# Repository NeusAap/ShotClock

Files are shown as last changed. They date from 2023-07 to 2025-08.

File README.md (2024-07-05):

# ShotClock hardware & software
This project entails the creation of a poker shot clock. The device is designed to manage the timing of player decisions during a poker game, enhancing the pace of play and ensuring fair timing for all participants. 

# Folder structure
1. `doc`: Contains design documents & notes/questions
2. `hw/ShotClockProject`: Contains KiCAD 7.0.6 design files for hardware
3. `hw/ShotClockProject/output`: Contains hardware output files (plots, PDFs etc.)
4. `sw`: contains STM32CubeIDE firmware

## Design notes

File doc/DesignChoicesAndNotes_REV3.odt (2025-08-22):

Shotclock design choices / notes / tasks REV 3

A product that displays a countdown timer on seven segment displays once a button has been pressed. The countdown will show a maximum of 99 seconds (2 digits), and each of these 2 digits should be present on 4 sides of the product (so a total of 8 seven segment displays).

A buzzer is added to audibily hear when the timer has ran out.

The product is designed to have a ‘main pcb’, which houses most electrical components. On each 90 degree edge of the main PCB, there will be a connector that connects to a set of 2 seven segment display digits.

See requirements below for more info.

The REV2 boards & encasing:

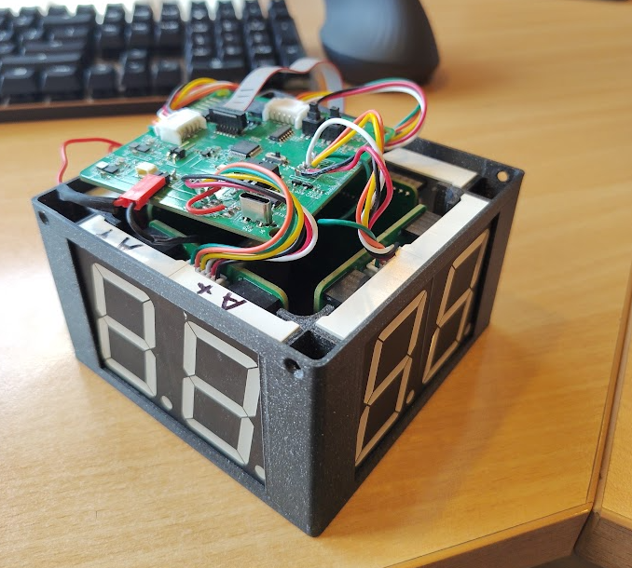
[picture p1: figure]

This document only contains updates, tasks etc for REV3! The information for REV2 is in the other .odt file.

# Updated requirements REV2 -> REV3

1. Battery powered, rechargable

1.1 USB type C, product must keep functioning while charging!

2. New buttons with new seperate connectors instead of buttons on PCB

3. More relaxed fitment in the encasing to reduce stress on the PCBs and the segment displays

# Research notes

## Notes for charging while using product

BQ25895 as charging IC is a good option

TPS61288RQQR as a high current buck converter

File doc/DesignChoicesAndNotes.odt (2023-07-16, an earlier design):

Shotclock design choices / notes

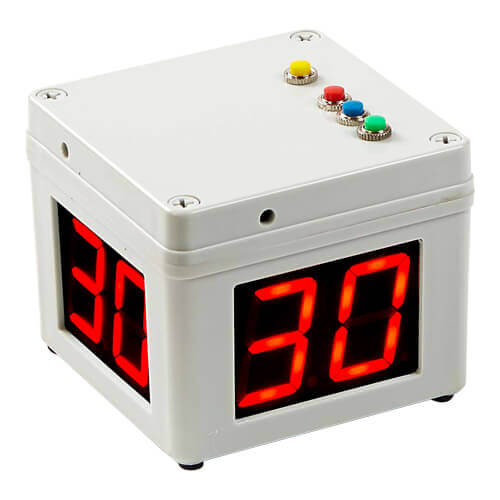
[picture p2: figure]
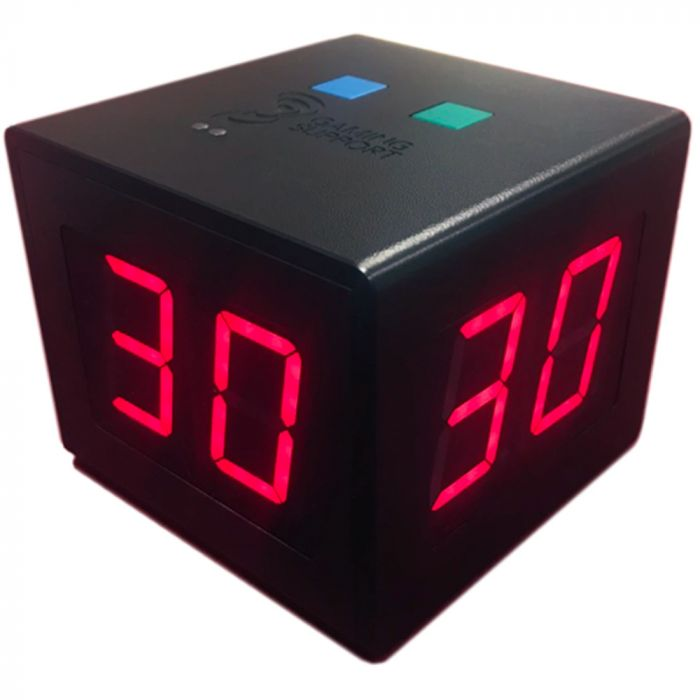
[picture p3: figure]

A product that displays a countdown timer on seven segment displays once a button has been pressed. The countdown will show a maximum of 99 seconds (2 digits), and each of these 2 digits should be present on 4 sides of the product (so a total of 8 seven segment displays).

A buzzer is added to audibily hear when the timer has ran out.

The product is designed to have a ‘main pcb’, which houses most electrical components. On each 90 degree edge of the main PCB, there will be a connector that connects to a set of 2 seven segment display digits.

See requirements below for more info.

# Requirements

1. Battery powered, rechargable

1.1 Li-Po would be nice, since large capacity and shitload of form factors

1.2 USB type C connector as charge plug (charging may stop usage of product if using li-po)

1.3 USB type C connector as USB D+/D- to MCU

2. Can drive 2x4 seven (actually, eight segment. They have a dot.) segment displays, with brightness control

3. LED to display battery < 20%

4. LED to display charging status (‘is charging’ and ‘is done charging’)

5. Switch (latching) to turn product on and off, while still being able to charge product (preferably in both the on and off state. But only off state is also fine for version 1).

6. Three functional buttons (momentary) with hardware debouncing

7. STM32 MCU, with SWD connector

8. UART header

9. Bootloader button to STM

10. Buzzer to indicate that the timer has ran out.

11. EEPROM to store user settings (atleast countdown time and buzzer on/off). So RTC registers of STM should be good enough.

# Battery charger & ADC charge status

## General info pages used

TP4056 as charging IC (https://dlnmh9ip6v2uc.cloudfront.net/datasheets/Prototyping/TP4056.pdf)

Page used on deciding charge current:

https://www.xtar.cc/news/What-Is-The-Best-Charging-Current-And-How-To-Calculate-The-Charging-Time-Of-Lithium-Battery-154.html

Disable system while charging battery:

https://www.microtype.io/lithium-ion-battery-charger-circuit-load-sharing/

Choosing battery of 1500 or 2000 mAh, since it is good middle-way between size, weight, price and capacity (should last the product more than long enough to be able to only charge it when systemload is off).

I got these in house: https://nl.aliexpress.com/i/1005005148897780.html?gatewayAdapt=glo2nld

With a thermistor in them. Calculations for this temp pin are in TEMP Pin NTC: R1, R2 calculation.

There will a 3 pin JST connector.

I’ve also added an extra 2 pin connector, since a load of cells don’t have a thermistor in them. A jumper is also present to pull the TEMP pin to ground, if no thermistor is to be used.

## TEMP Pin NTC: R1, R2 calculation

The batteries I have, have a 10k NTC at room temp. I don’t know the specifics, because it is a chinese battery, without good datasheet. Internet says “10K NTC usually has 3977K Thermistor Beta Value” (https://www.eevblog.com/forum/projects/ntc-thermistor-resistance-(li-ion-charging)/).

The datasheet of the TP4056 mentions: “If TEMP pin’s voltage is below 45% or above 80% of supply voltage VIN for more than 0.15S, this means temp is to low or high”.

So if assuming that the following is true:

For 45°C the thermistor resistance is about 4k2.

For 5°C the thermistor resistance is about 26k.

(at ambient room temp of +/- 20°C, the resistance was about 7k8, measured myself, so this assumption sounds about right)

I’ve converted the resistance calculator from above post: https://www.best-microcontroller-projects.com/tp4056-page2.html into Python code (inserted as OLE object, also found on my GitHub):

Then using the following input values for the Python script:

vratio1 = 0.45

vratio2 = 0.80

ratio_tol1 = 0.01

ratio_tol2 = 0.05

Rntc_min = 4200

Rntc_max = 26000

Gives the following closest E48 resistors (just as in the article. Atleast I know how to calculate this now hahaha):

r1 4780 r2 86600 Rntc1 4.2e3 Rntc2 26e3

I am also adding a jumper, to switch off the whole functionality as well. Both to support 2 pinned batteries, and to disable the temp sensing, if these assumption and/or calculations are wrong.

## Battery charge reading & battery lvl status LED

To read the amount of charge in the battery, I want to use the ADC of the STM32.

This article was used as example: https://vivonomicon.com/2019/10/15/reading-battery-voltage-with-the-stm32s-adc/

It mentions that: “if you use smaller resistor values for the voltage divider, you use more current, but the sampling can be faster”. A commentor on that post replied: “You can use larger resistors (i.e. 1M) in the divider and still use short sampling times if you add a small capacitor (1n-100n). [between the Analog pin and ground, to buffer so the ADC peripheral gets current more quickly. Instead of via the high resistance path of the voltage divider]”.

So that is what is implemented. A 1:1 voltage division (a single Lithium cell get to a max of 4.2V, so divided by 2 will give a max of 2.1V, which the analog pins easily accept), with large resistance values (1M) and a 100n capacitor between the analog ADC peripheral and GND.

Max current leakage would be:

4.2 = I * 2000000

I = 0.0000021 amps (or 2.1 microamps).

Should be reasonable for a 1500mAh battery (or is it smart to increase the resistance values & capacitor value even more, to reduce the current leakage even more?).

And for the battery level status led:

Assuming a forward voltage drop of 2.0 volts and a forward current of 10 mA, we can calculate the resistor value using Ohm's Law (V = IR).

Rearranging the formula, we get R = V / I.

R = (Vsupply - Vf) / I

R = (3.3V - 2.0V) / 0.01A

R = +/- 130 Ω (130 is closest E48 std. value.)

# Voltage regulator (3v3)

TPS63000, variable output DC/DC buck boost.

Variable output calculation

From datasheet:

8.2.2 Detailed Design Procedure

8.2.2.1 Programming the Output Voltage

“Within the TPS6300x family, there are fixed and adjustable output voltage versions available. To properly configure the fixed output voltage devices, the FB pin is used to sense the output voltage. This means that it must be connected directly to VOUT. At the adjustable output voltage versions, an external resistor divider is used to adjust the output voltage. The resistor divider must be connected between VOUT, FB and GND. When the output voltage is regulated properly, the typical value of the voltage at the FB pin is 500 mV. The maximum recommended value for the output voltage is 5.5 V. The current through the resistive divider should be about 100 times greater than the current into the FB pin. The typical current into the FB pin is 0.01 μA, and the voltage across the resistor between FB and GND, R2 , is typically 500 mV. Based on those two values, the recommended value for R2 should be lower than 500 kΩ, in order to set the divider current at 1 μA or higher. TI recommends to keep the value for this resistor in the range of 200 kΩ. From that, the value of the resistor connected between VOUT and FB, R1 , depending on the needed output voltage (VOUT), can be calculated using Equation 1. (1) If as an example, an output voltage of 3.3 V is needed, a 1-MΩ resistor should be chosen for R1 . To improve control performance using a feedforward capacitor in parallel to R1 is recommended. The value for the feedforward capacitor can be calculated using Equation 2.”

This data from the datasheet has been used to calculate R2 and Cff, see R2 calculation and Cff calculation.

## R2 calculation

Wanted Vout is 3v3.

R1 = 1M (according to datasheet 8.2.2.1)

R2 = ?

Vout = 3.3V

Vfb = 0.5V (typical value from datasheet 8.2.2.1)

Solving for R2:

R2 = (Vfb * R1) / (Vout - Vfb )

R2 = (0.5 * 1000000) / (3.3 – 0.5) = 178571,4285714286 ohms.

Solved for Vout (to make sure I did not make a solving mistake):

Vout = (Vfb * (R1 + R2) ) / R2

Vout = (0.5 * (1000000 + 178000)) / 178000 = 3,308988764044944 = 3.3v.

So chosen R2 = 178k.

## Cff calculation

2.2us = 0.0000022 s

R1 = 1000000 ohm

Cff = 2.2us / R1 = 0.0000022 / 1000000 = 0.0000000000022 F

0.0000000000022 F = 2.2 pF

So Cff should be 2.2pF

# Vbat pin on MCU

I’d like to connect the Vbat pin on the MCU, to the Li-Ion battery. This way I don’t have to put an extra coin-cell in, and I can still use the RTC functionality on the MCU.

The datasheet mentions the following important information on the RTC and backup registers (2.3.16, but I’ve marked important keywords here):

“+/- 2.2 uA power usage at 3v3 (see figure 16 of datasheet)

VBAT Backup operating voltage min: 1.8V and max 3.6V.

The RTC and the backup registers are supplied through a switch that takes power either on VDD supply when present or through the VBAT pin. The backup registers are forty-two 16-bit registers used to store 84 bytes of user application data when VDD power is not present. They are not reset by a system or power reset, and they are not reset when the device wakes up from the Standby mode. The real-time clock provides a set of continuously running counters which can be used with suitable software to provide a clock calendar function, and provides an alarm interrupt and a periodic interrupt. It is clocked by a 32.768 kHz external crystal, resonator or oscillator, the internal low-power RC oscillator or the high-speed external clock divided by 128. The internal low-speed RC has a typical frequency of 40 kHz. The RTC can be calibrated using an external 512 Hz output to compensate for any natural quartz deviation. The RTC features a 32-bit programmable counter for long term measurement using the Compare register to generate an alarm. A 20-bit prescaler is used for the time base clock and is by default configured to generate a time base of 1 second from a clock at 32.768 kHz.”

So:

1. No higher than 3.6V (Li-Po can get up to 4.2V, so we need a lower voltage).

2. Low power consumption, which is nice. LDO would be good option

3. 84 bytes of user data is more than enough. This means no extra EEPROM chip is needed.

4. Can be clocked by internal clock, or High-Speed External. Since I see no use for a really precise, non-drifting clock, this means that I can omit the 32.768kHz crystal from the design.

Only problem, is the voltage.

A voltage division would probably not work here, since the voltage would keep changing when the battery drains. This would probably give weird clock issues (I don’t need a really stable RTC clock, but a sort-off stable RTC would be nice).

So next best option would probably to use a small LDO. The RTC pin does not use to much current, so the inefficiency does not matter to much.

LD39015M33R is chosen, since this has input range of 1.8 to 5.5v and a stable output of 3v3. Very low quiescent current (18 µA typ. at no load, 38 µA typ. at 150 mA load, 1 µA max. in OFF mode) and also 150mA output current, which should be way more than enough.

# Momentary buttons and hardware debouncing

I want 3 digital input momentary buttons, with hardware debouncing integrated into the PCB.

Schmitt Trigger IC chosen for debouncing: STM m74hc14yrm13tr.

Because the internet said this IC is great for button removing hysterisis at 3v3 levels since it is a really fast schmitt trigger IC. The IC doesn’t need additional configuration. Also the IC is ok in terms of availability.

https://www.st.com/resource/en/datasheet/m74hc14.pdf

I’ve used ‘snapeda.com’ to create a schematic symbol (footprint was already available). Quite useful stuff: https://www.snapeda.com/parts/M74HC14YRM13TR/STMicroelectronics/view-part/

# Buzzer

To make sure the buzzer does not pull to much current from the MCU, an NPN transistor is used:

Also a flyback diode is placed between buzzer pins, to act as a bypass if the magnetic field collapses, to not damage the transistor.

A current limiting resistor of 1k ohm is used for the base pin of the transistor.

Then 3v3 is connected to GND, via the transistor.

Since the chosen buzzer (see Footprint / part choices) only uses +/- mA, almost all transistors should be fine.

# Connectors to seven (eight) segment displays

The used segment displays are common cathode: https://t.ly/1rQHq (short URL, because AliExpress creates huge URLs).

There are 8 segments (7 for the digit, 1 for a dot), and two ground pins per display:

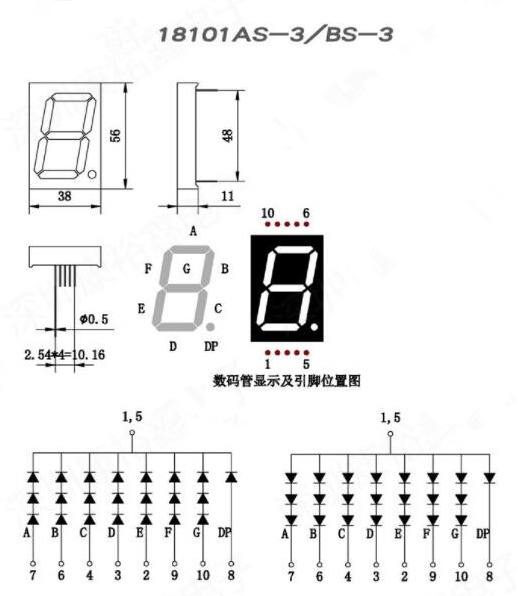
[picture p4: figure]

PIN 1 = GROUND

PIN 5 = GROUND

PIN 2 = E

PIN 3 = D

PIN 4 = C

PIN 6 = B

PIN 7 = A

PIN 8 = DP

PIN 9 = F

PIN 10 = G

The displays will be mounted on seperate PCB’s for easy product assembly (the displays have pins, so the PCB’s will have header sockets). Then, each segment PCB will be connected to the main shotclock PCB, also using header pins/sockets.

To minimize noise, low impedance paths and reduces the chances of ground bounce or voltage fluctuations, I’ll try to add as much ground pins between the two PCB’s as possible.

Each segment PCB will mount two segment displays (each display should be able to show a different digit). Each shotclock will have 4 segment PCB’s mounted in 90° offset rotation from main PCB center. These all show the same 2 sets of digits (hense, 16 signals needed in total). The transistors will be mounted on the segment display PCB, not on the main PCB. Main PCB will only provide power, GND & PWM signals.

A good connector I could find, is the male and female 2x10 p=2.54mm header pins/sockets.

Since there are 16 (PWM) signal lines needed between the boards, 1 3v3 line, this leaves 3 GND pins.

# Footprint / part choices

## Main PCB

USB c female: ~~https://jlcpcb.com/partdetail/Molex-1054500101/C134092~~ ~~OR~~ https://jlcpcb.com/partdetail/ShouHan-TYPE_C_16P_LTH68/C5187468

Buzzer (9x9mm SMD): https://jlcpcb.com/partdetail/1056281-Cy_SMD_90193040/C968734

Capacitors: 0603 (actually not really backed by reason, see Thoughts and questions).

Resistors: 0603 (actually not really backed by reason, see Thoughts and questions).

LEDs: 0603

- Green: https://jlcpcb.com/partdetail/EverlightElec-19_217_GHC_YR1S23T/C72043
- Orange: https://jlcpcb.com/partdetail/EverlightElec-19_21SOCTR8/C264451
- Red: https://jlcpcb.com/partdetail/EverlightElec-19_213_R6C_AN1P23T/C128250

Diode (for buzzer bypass): SOD-323, because it is readily available: https://jlcpcb.com/partdetail/2485-1N4148WS/C2128

Ferrite Bead (0603): https://jlcpcb.com/partdetail/taitech-HCB1608KF121T20/C127301

TP4056 (SOP8): https://jlcpcb.com/partdetail/772193-TP4056/C725790

Inductor for voltage regulator (3012S): https://jlcpcb.com/partdetail/Tdk-VLS3012HBX2R2M/C404494

STM32F103RCT6 (LQFP-64, 10x10): https://jlcpcb.com/partdetail/Stmicroelectronics-STM32F103RCT6/C8323

Voltage regulator TPS63000 (SON-10-EP, 3.1x3.1): https://jlcpcb.com/partdetail/TexasInstruments-TPS63000DRCR/C24966

Smitt trigger M74HC14YRM13TR(SO-14): https://jlcpcb.com/partdetail/Stmicroelectronics-M74HC14YRM13TR/C157450

LDO 3v3 for battery to Vbat pin, LD39015M33R (SOT-23-5): https://jlcpcb.com/partdetail/Stmicroelectronics-LD39015M33R/C2798212

16Mhz 10pf Crystal (3225-4p): https://jlcpcb.com/partdetail/YangxingTech-X322516MMB4SI/C112972

Boot switch (latching, slide, 2 choices with same footprint):

~~https://jlcpcb.com/partdetail/gswitch-MK_12C02G025/C778186~~ ~~OR~~ https://jlcpcb.com/partdetail/XkbConnectivity-SS_3292S_L2B/C500057

Main power switch (SMD, push latching):

https://jlcpcb.com/partdetail/gswitch-PS_5824SVB6PL/C5155575

Fucntional momentary buttons(B3U-1000): https://jlcpcb.com/partdetail/OmronElectronics-B3U1000P/C231329

Transistor for buzzer (SOT-23): https://jlcpcb.com/partdetail/Shikues-MMBT3904/C111113

MOSFET for load disabling while charging: https://jlcpcb.com/partdetail/Pjsemi-PJM2301PSA/C411715

Pin header display PCBs male:

~~https://jlcpcb.com/partdetail/boomele_boom_Precision_elec-C85667/C85667~~

or

https://jlcpcb.com/partdetail/Liansheng-PH00041/C2830008

Pin header display PCBs female:

~~https://jlcpcb.com/partdetail/ConnflyElec-DS1023_212SF11/C92265~~

or

https://jlcpcb.com/partdetail/Dealon-DW254W_22_2085/C2936006

Pin header 2x7 stdc14 debugger connector:

https://jlcpcb.com/partdetail/Hctl-PZ127_2_07S/C3975190

Pin header 1x6 angled p2.54mm for UART:

https://jlcpcb.com/partdetail/boomele_boom_Precision_elec-C56816/C56816

Pin header 1x3 angled p2.54 for battery TEMP on/off:

https://jlcpcb.com/partdetail/boomele_boom_Precision_elec-C92159/C92159

Pin header 1x3 p1.00m for battery (JST plug):

~~https://jlcpcb.com/partdetail/171769-BM03B_SRSS_TB_LF_SN/C160389~~

or

https://jlcpcb.com/partdetail/171783-SM03B_SRSS_TB_LF_SN/C160403

pin header 1x2 p2.54 for battery:

https://jlcpcb.com/partdetail/cjt_changjiang_connectors-A2005WR2P/C225269

# Thoughts and questions

## Main PCB

1. Does the LDO for the Vbat pin and batt+ connection make sense? Or should I just use voltage division or a switching regulator for this? (high clock accuracy is not needed, just a clock, and a way to power backup registers when 3v3 is off)

2. Is it smart to add reverse polarity protections, or ESD protections? If so, where?

3. Any handy places to put a test point, that I have forgotten? (Testpoints for a pin-bed is a bit out of scope for V1, might add this in later though).

4. For the ADC voltage divider, what stops me from increasing resistance and buffer capacitor even more, to get less current leakage?

5. Is it a good idea to create a hard shut-off for the li-ion when it is for example < 3.0V? If so, what is a good way to do so? (the charge IC TP4056 does not have such functionality built-in).

6. Should my jumper system, to shut off the TEMP sensing of the TP4056 work? By just pulling the ‘IC_TEMP’ label to GND, the whole ‘BATT_NTC’ label, and that voltage divider will effectivly be ‘disabled’ right? Or am I also pulling the ‘Vbus’ to GND in that case?

7. When do I use larger/smaller packages for passive components? The current package sizes are just ‘randomly’ selected.

8. Do I connect USB c shield to ground? I guess so?

9. What is important to look for in an inductor? VLF4012-2R2 is recommended by datasheet for L1. VLS3012HBX-2R2M seems to roughly have the same characteristics, and is available.

10. On Page 5 (Schmitt trigger), I have a pull-up to 3v3 (47k) and a smaller 10k to create path of least resistance. Is this assumption correct? Or is the 10k not needed?

11. On Page 5 (Schmitt trigger), I there is a voltage division on pin 1 of the switches. Does it matter? I would’nt think so, since 3v3 will flow to the pin of the Schmitt trigger when the button is not pressed, else to ground.

12. Current limiting for the Schmitt trigger shouldn’t matter to much, right?

13. Is 1 3v3 pin, and 3 GND pins enough for the display PCB?

14. Any comments on the component PCB placements? I tried to put decoupling capacitors as close to their respective pins. Same for crystal oscillator. USB D+ and D- are also placed as close to the MCU pin as possible.

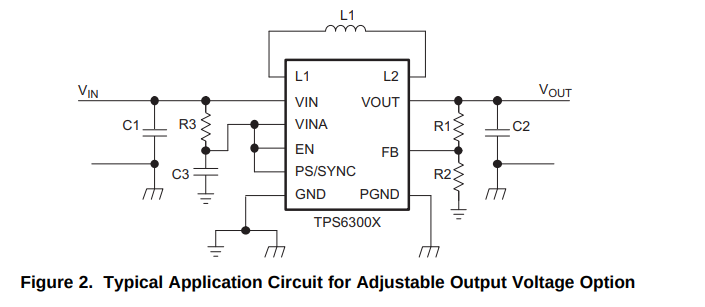
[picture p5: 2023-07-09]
doc/ShotclockDatasheetScreenshots/TPS6300x_VoltageRegulator.png

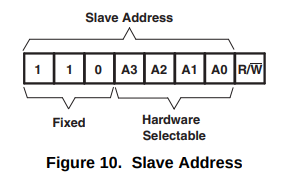
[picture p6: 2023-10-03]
doc/ShotclockDatasheetScreenshots/TLC_I2C_AddressSelection.png

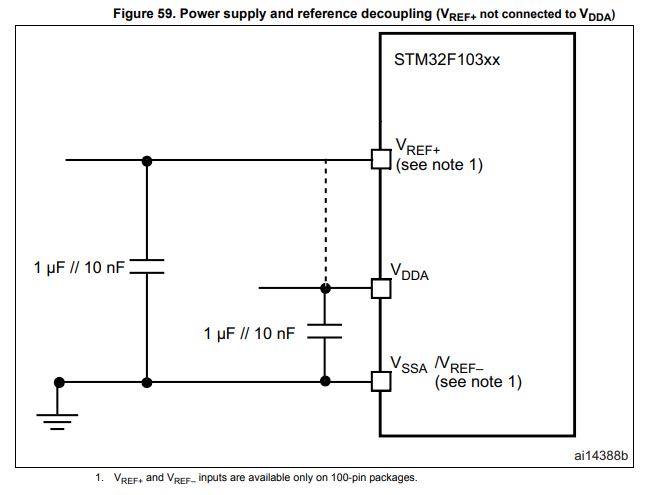
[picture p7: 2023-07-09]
doc/ShotclockDatasheetScreenshots/Vdda_Decoupling.png

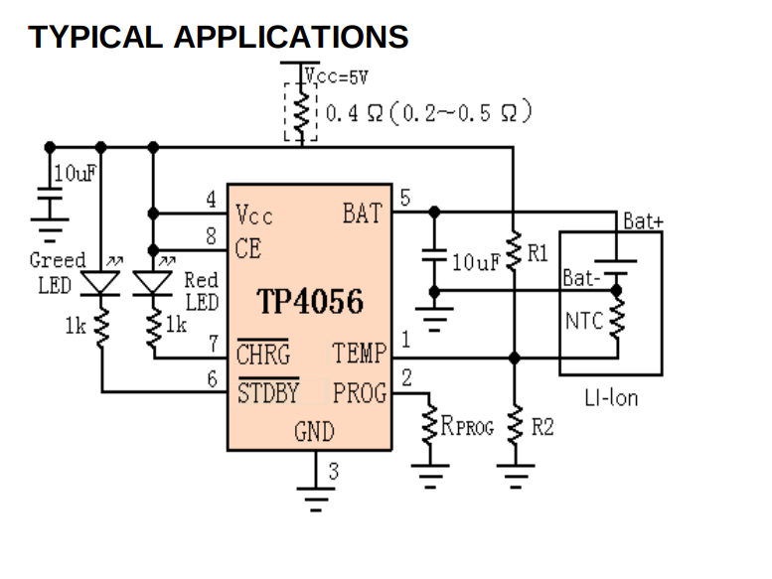
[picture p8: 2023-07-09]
doc/ShotclockDatasheetScreenshots/LiIonCharger.png

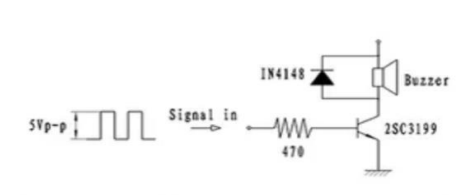
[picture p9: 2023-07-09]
doc/ShotclockDatasheetScreenshots/BuzzerExample.png

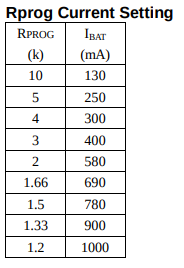
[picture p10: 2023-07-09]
doc/ShotclockDatasheetScreenshots/TP4056_Rprog_values.png

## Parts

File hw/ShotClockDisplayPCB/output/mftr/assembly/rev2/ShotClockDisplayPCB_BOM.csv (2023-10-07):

Comment | Designator | Footprint | LCSC Part #
100p Unpolarized capacitor | C1 | C_0402_1005Metric | C106200
10u Unpolarized capacitor | C2 | C_0402_1005Metric | C315248
Conn_01x02_Pin Generic connector, single row, 01x02, script generated | J1,J2,J3,J4 | PinHeader_1x02_P2.54mm_Horizontal | C492410
Conn_01x05_Socket Generic connector, single row, 01x05, script generated | J5,J6,J7,J8 | PinSocket_1x05_P2.54mm_Vertical | C2897368
10k Resistor | R1,R2,R3,R4 | R_0402_1005Metric | C25744
100r Resistor | R5,R6 | R_1210_3225Metric | C2933827
1k Resistor | R7 | R_0402_1005Metric | C11702
S6B-PH-K-S-(LF)(SN) | U1 | CONN-TH_6P-P2.00_S6B-PH-K-S-LF-SN | C157920
TLC59116IRHBR | U2 | PG-VQFN-32_L5.0-W5.0-P0.50-BL-EP3.6 | C575579

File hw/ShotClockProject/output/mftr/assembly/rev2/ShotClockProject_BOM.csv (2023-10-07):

Comment | Designator | Footprint | LCSC Part #
CY-SMD-9019-3040 | BUZZER1 | BUZ-SMD_L9.0-W9.0-P8.00-LS9.3_CY | C968734
10n Unpolarized capacitor | C1,C16 | C_0402_1005Metric | C15195
1u Unpolarized capacitor | C2,C3,C9,C12 | C_0402_1005Metric | C52923
4.7u Unpolarized capacitor | C4 | C_0402_1005Metric | C23733
100n Unpolarized capacitor | C5,C6,C10,C11,C15,C27,C28,C29 | C_0402_1005Metric | C1525
6p Unpolarized capacitor | C7,C8 | C_0402_1005Metric | C1575
10u Unpolarized capacitor | C13,C14 | C_0402_1005Metric | C15525
2.2p Unpolarized capacitor | C17,C22 | C_0402_1005Metric | C1559
10u Unpolarized capacitor | C18,C19,C20,C23,C24,C25 | C_0603_1608Metric | C96446
0.1u Unpolarized capacitor | C21,C26 | C_0402_1005Metric | C1525
Orange LED Light emitting diode | D1 | LED_0603_1608Metric | C264451
G_LED Light emitting diode | D2,D4,D5 | LED_0603_1608Metric | C72043
R_LED Light emitting diode | D3 | LED_0603_1608Metric | C128250
1N4148 100V 0.15A standard switching diode, DO-35 | D6 | D_SOD-323 | C2128
120R Ferrite bead | FB1 | L_0603_1608Metric | C127301
TP4056-42-ESOP8_Rearanged PMIC - Battery Management ESOP-8 RoHS | IC1 | Texas_HSOP-8-1EP_3.9x4.9mm_P1.27mm | C725790
Conn_01x06_Pin Generic connector, single row, 01x06, script generated | J1 | PinHeader_1x06_P2.54mm_Horizontal | C56816
Conn_ST_STDC14 ST Debug Connector, standard ARM Cortex-M SWD and JTAG interface plus UART | J2 | PinHeader_2x07_P1.27mm_Vertical_SMD | C3975190
SM03B-SRSS-TB(LF)(SN)(P) | J3 | CONN-SMD_SM03B-SRSS-TB-LF-SN-P | C160403
Conn_01x02_Pin Generic connector, single row, 01x02, script generated | J4,J7 | PinHeader_1x02_P2.54mm_Horizontal | C492410
USB4120-03-C_REVA | J6 | GCT_USB4120-03-C_REVA_With3DModel | C5187468
2.2uH Inductor | L1,L2 | L_Sunlord_SWPA3012S | C404494
Q_PMOS_SGD P-MOSFET transistor, source/gate/drain | Q1 | TO-263-2 | C33903
Q_NPN_BCE NPN transistor, base/collector/emitter | Q2,Q3,Q4 | SOT-23 | C111113
0R Resistor | R1,R2,R3,R4 | R_0402_1005Metric | C17168
1.5k Resistor | R5,R6 | R_0402_1005Metric | C25867
100R Resistor | R7,R9,R23,R27 | R_0402_1005Metric | C25076
10k Resistor | R8,R19,R20,R31,R32,R33,R38,R39 | R_0402_1005Metric | C25744
0.4R Resistor | R10 | R_0402_1005Metric | C27147
100k Resistor | R11,R16,R17 | R_0402_1005Metric | C25741
1k Resistor | R12,R13,R14,R15,R35 | R_0402_1005Metric | C105637
1k2 Resistor | R18 | R_0402_1005Metric | C25862
4780R Resistor | R21 | R_0402_1005Metric | C25900
86k6 Resistor | R22 | R_0402_1005Metric | C852935
1M Resistor | R24,R28 | R_0402_1005Metric | C144787
178k Resistor | R25 | R_0402_1005Metric | C185459
1k5 Resistor | R26,R30 | R_0402_1005Metric | C25867
110k Resistor | R29 | R_0402_1005Metric | C25745
300R Resistor | R34 | R_0402_1005Metric | C25102
5k1 Resistor | R36,R37 | R_0402_1005Metric | C25905
TK-6580S-1 | SW1 | SW-SMD_TK-6580S-1 | C528774
SW_SPDT Switch, single pole double throw | SW2 | SW_SPDT_PCM12_Upwards | C500057
TK-6580S-2 | SW3,SW4,SW5 | SW-SMD_TK-6580S-2 | C528775
TestPoint test point | TP2,TP5 | TestPoint_Pad_D1.0mm
STM32G070CBTx STMicroelectronics Arm Cortex-M0+ MCU, 128KB flash, 36KB RAM, 64 MHz, 2.0-3.6V, 43 GPIO, LQFP48 | U1 | LQFP-48_7x7mm_P0.5mm | C529338
LD39015M33R 150mA low quiescent current low noise voltage regulator, Fixed Output 3.3V, SOT-23-5 | U2 | SOT-23-5 | C2798212
TPS63000 Buck-Boost Converter, 1.8-5.5V Input Voltage, 1.7A Switch Current, 3.3V Output Voltage, VSON-10 | U3,U4 | Texas_DRC0010J_Altered | C24966
M74HC14YRM13TR | U5 | SOIC-14_3.9x8.7mm_P1.27mm | C157450
S6B-PH-K-S-(LF)(SN) | U6,U7,U8,U9 | CONN-TH_6P-P2.00_S6B-PH-K-S-LF-SN | C157920
16MHz Four pin crystal, GND on pins 2 and 4 | Y1 | Crystal_SMD_3225-4Pin_3.2x2.5mm | C112972

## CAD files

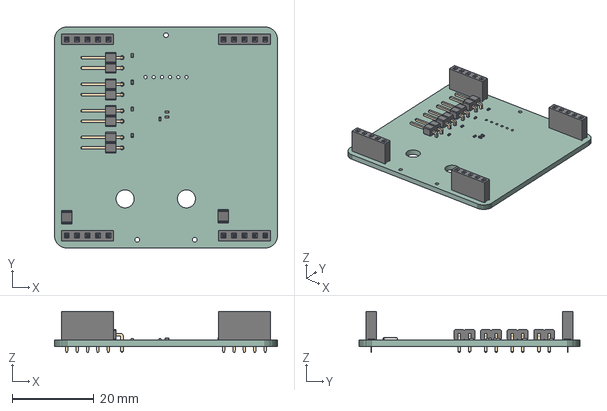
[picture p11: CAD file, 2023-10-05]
hw/ShotClockDisplayPCB/output/3d/ShotClockDisplayPCB.step
54.5 x 54.0 x 10.1 mm
ShotClockDisplayPCB PCB

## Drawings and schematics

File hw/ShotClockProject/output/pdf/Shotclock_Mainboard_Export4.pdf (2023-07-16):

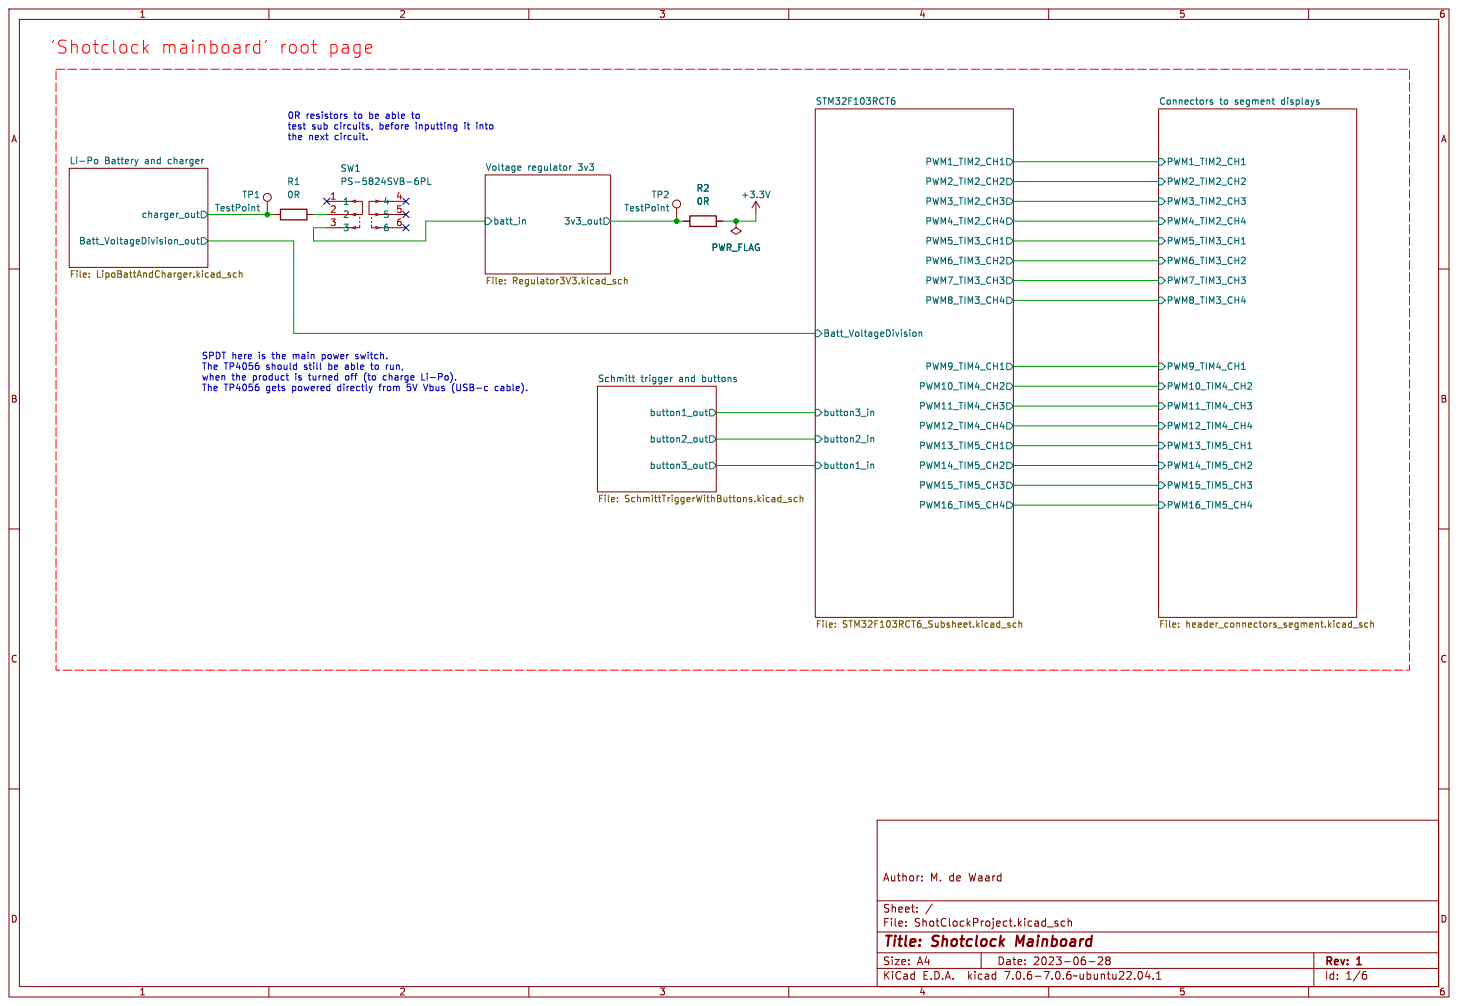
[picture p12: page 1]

button1_out button2_out button3_out Schmitt trigger and buttons File: SchmittTriggerWithButtons.kicad_sch

Id: 1/6 Title: Shotclock Mainboard

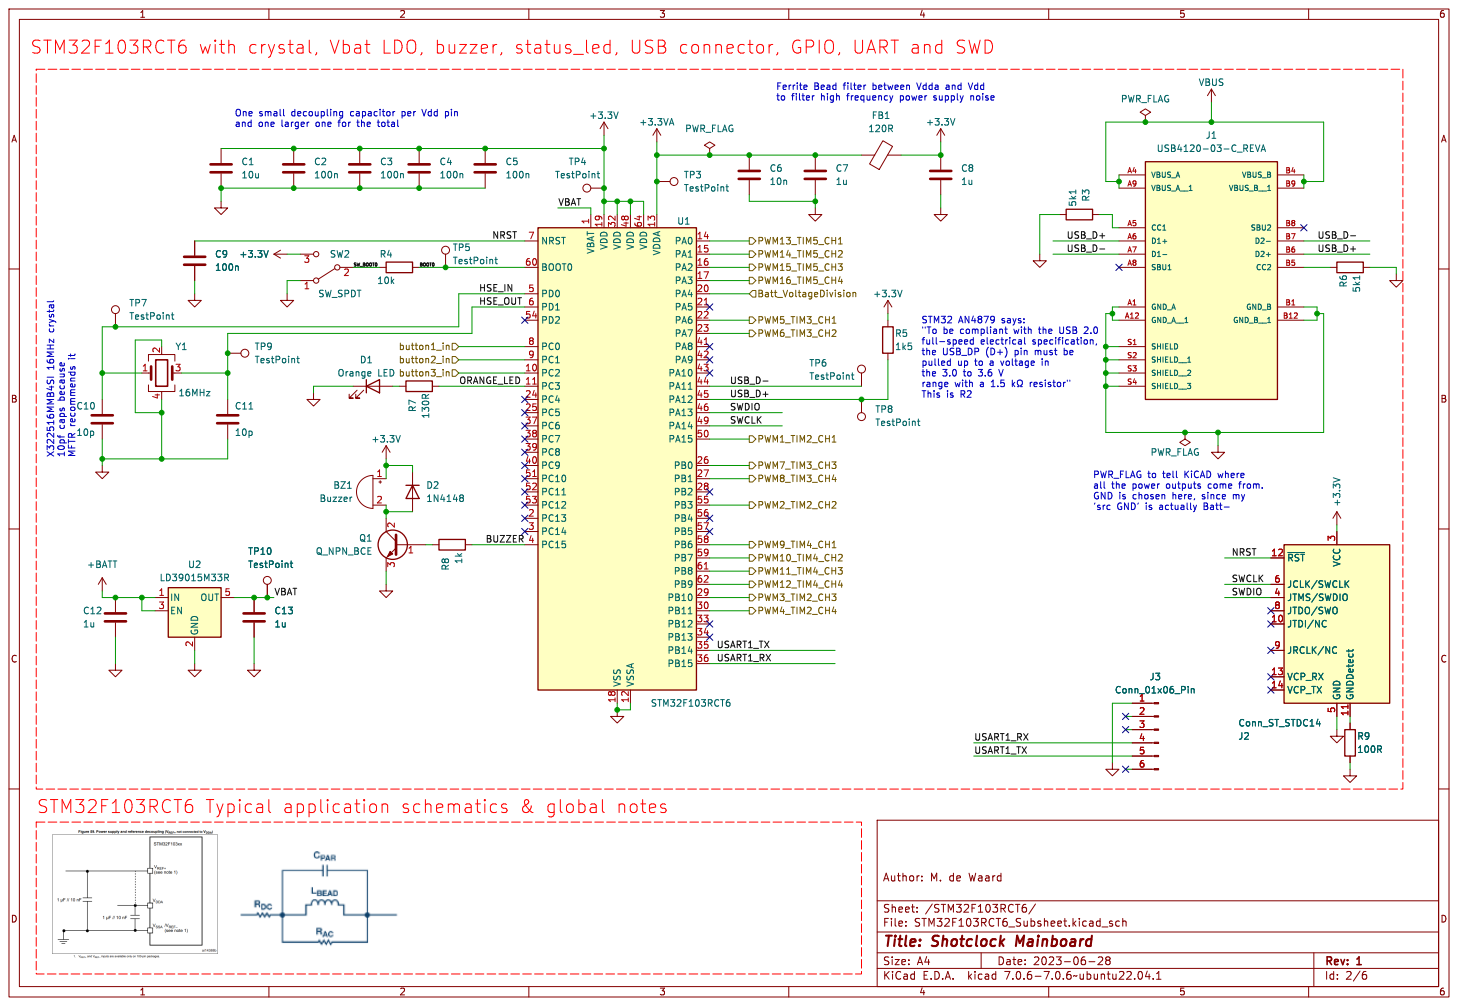
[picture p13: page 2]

Ferrite Bead filter between Vdda and Vdd

1 PC2 10 PC3 11 VSSA 12 VDDA 13 PA0 14 PA1 15 PA2 16 PA3 17 VSS 18 VDD 19 PC13 2 PA4 20 PA5 21 PA6 22 PA7 23 PC4 24 PC5 25 PB0 26 PB1 27 PB2 28 PB10 29 PC14 3 PB11 30 VDD 32 PB12 33 PB13 34 PB14 35 PB15 36 PC6 37 PC7 38 PC8 39 PC15 4 PC9 40 PA8 41 PA9 42 PA10 43 PA11 44 PA12 45 PA13 46 VDD 48 PA14 49 PD0 5 PA15 50 PC10 51 PC11 52 PC12 53 PD2 54 PB3 55 PB4 56 PB5 57 PB6 58 PB7 59 PD1 6 BOOT0 60 PB8 61 PB9 62 VDD 64 NRST 7 PC0 8 PC1 9 U1 STM32F103RCT6

J2Conn_ST_STDC14 R5
the USB_DP (D+) pin must be
pulled up to a voltage in
the 3.0 to 3.6 V

all the power outputs come from. GND is chosen here, since my

Id: 2/6 Title: Shotclock Mainboard

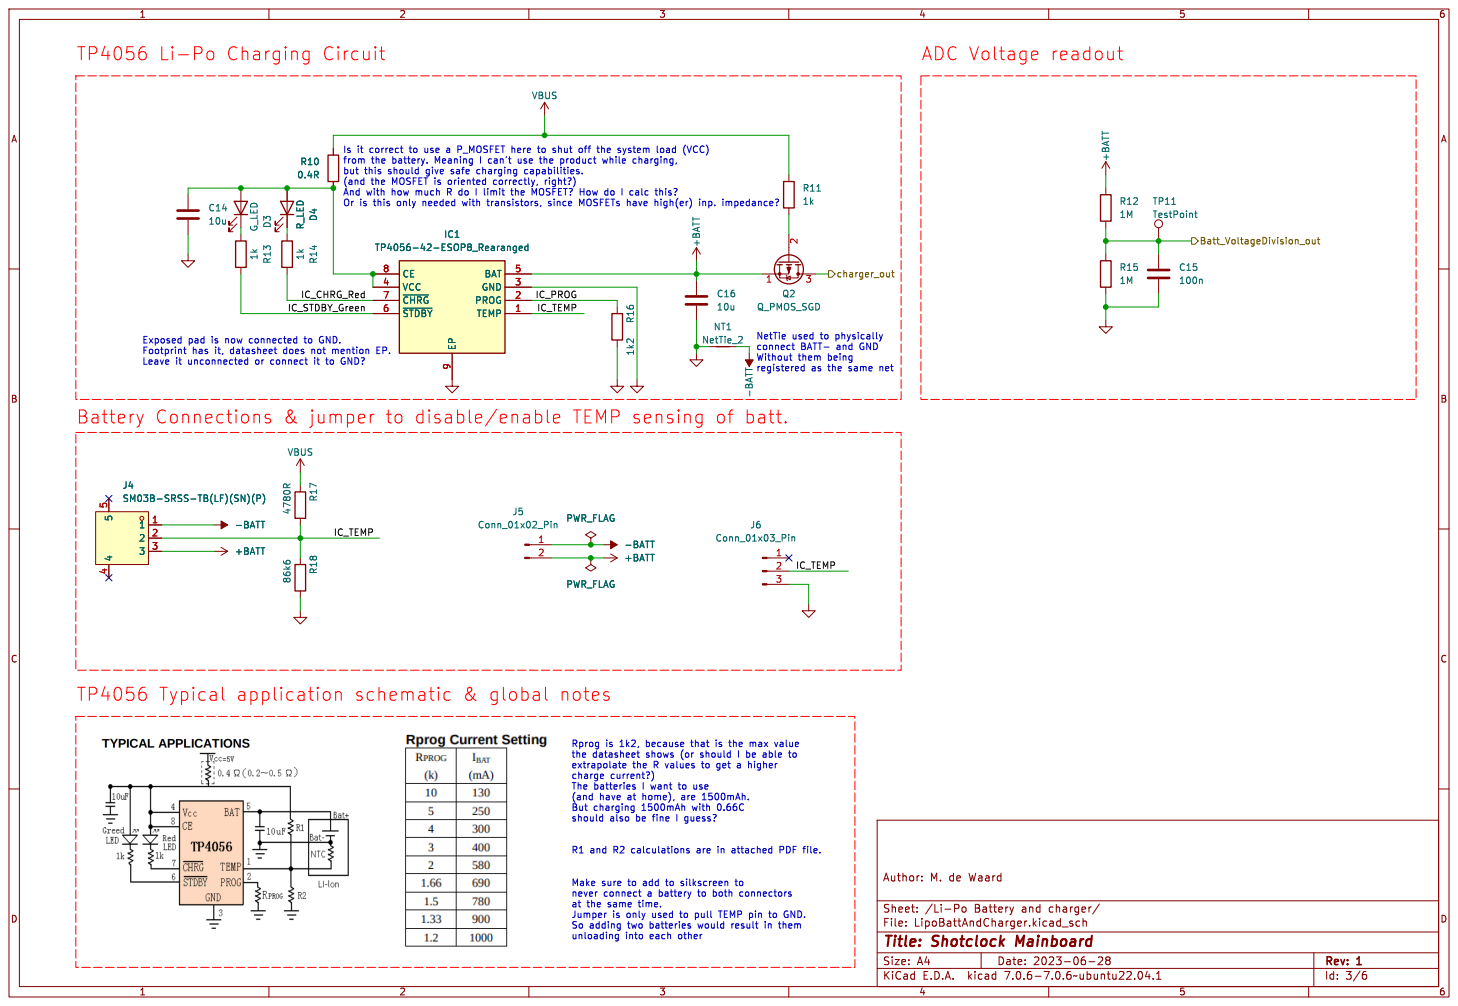
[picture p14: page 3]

TP4056 Li-Po Charging Circuit

Is it correct to use a P_MOSFET here to shut off the system load (VCC)

NetTie used to physically
connect BATT- and GND Without them being

J4SM03B-SRSS-TB(LF)(SN)(P) 1

Rprog is 1k2, because that is the max value

Id: 3/6 Title: Shotclock Mainboard

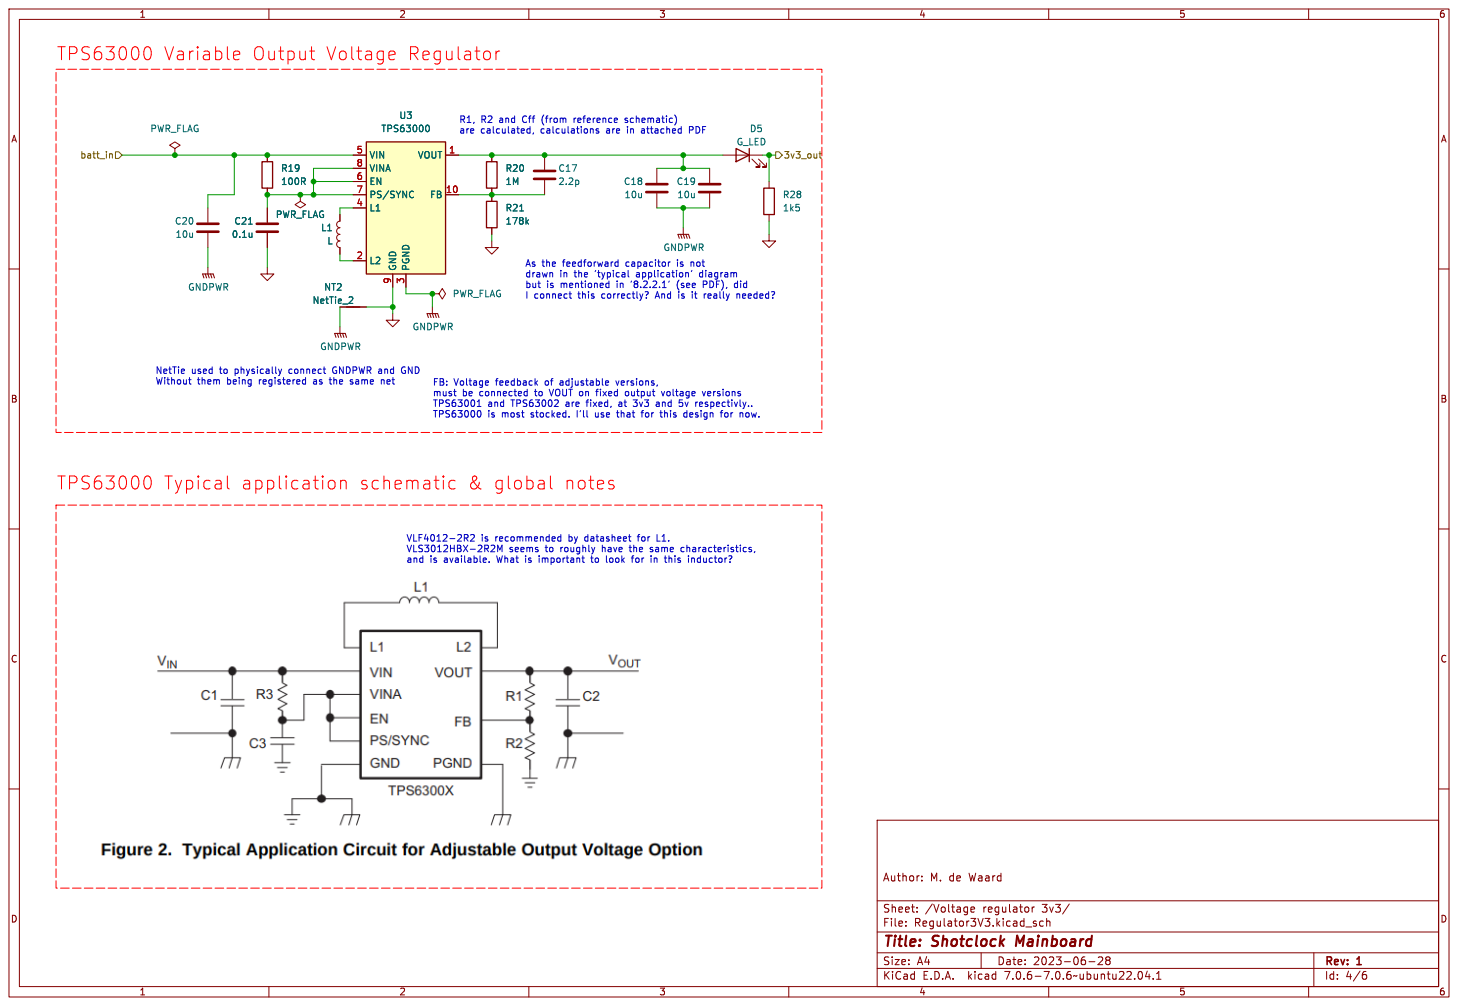
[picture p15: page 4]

Id: 4/6 Title: Shotclock Mainboard

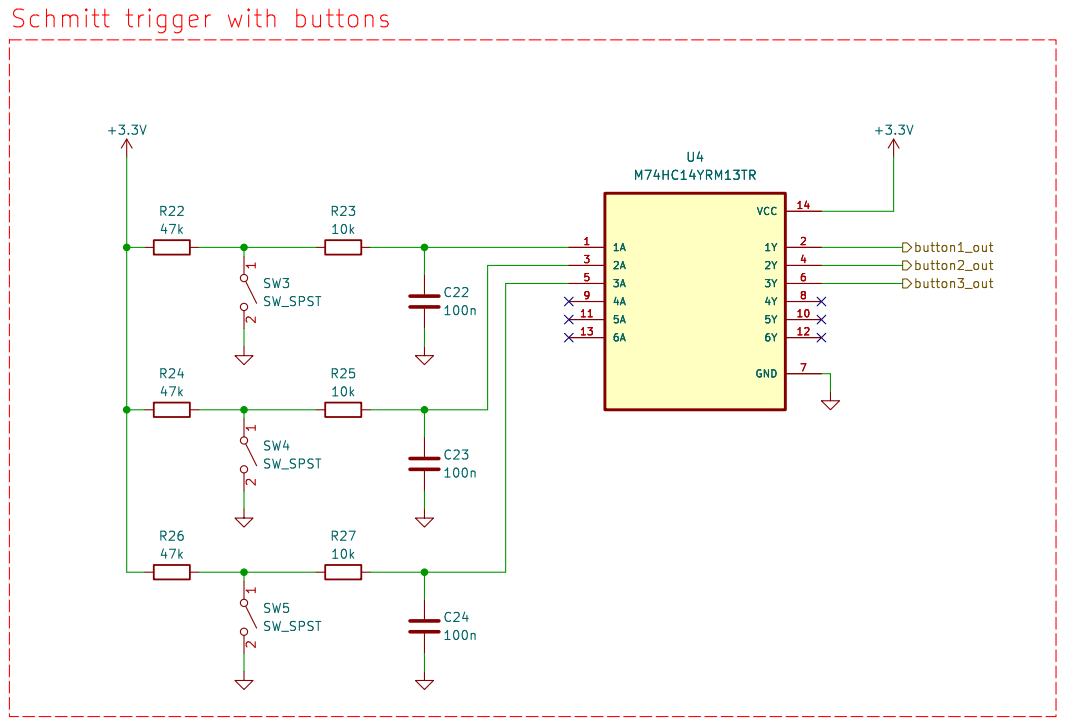
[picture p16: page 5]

Id: 5/6 Title: Shotclock Mainboard

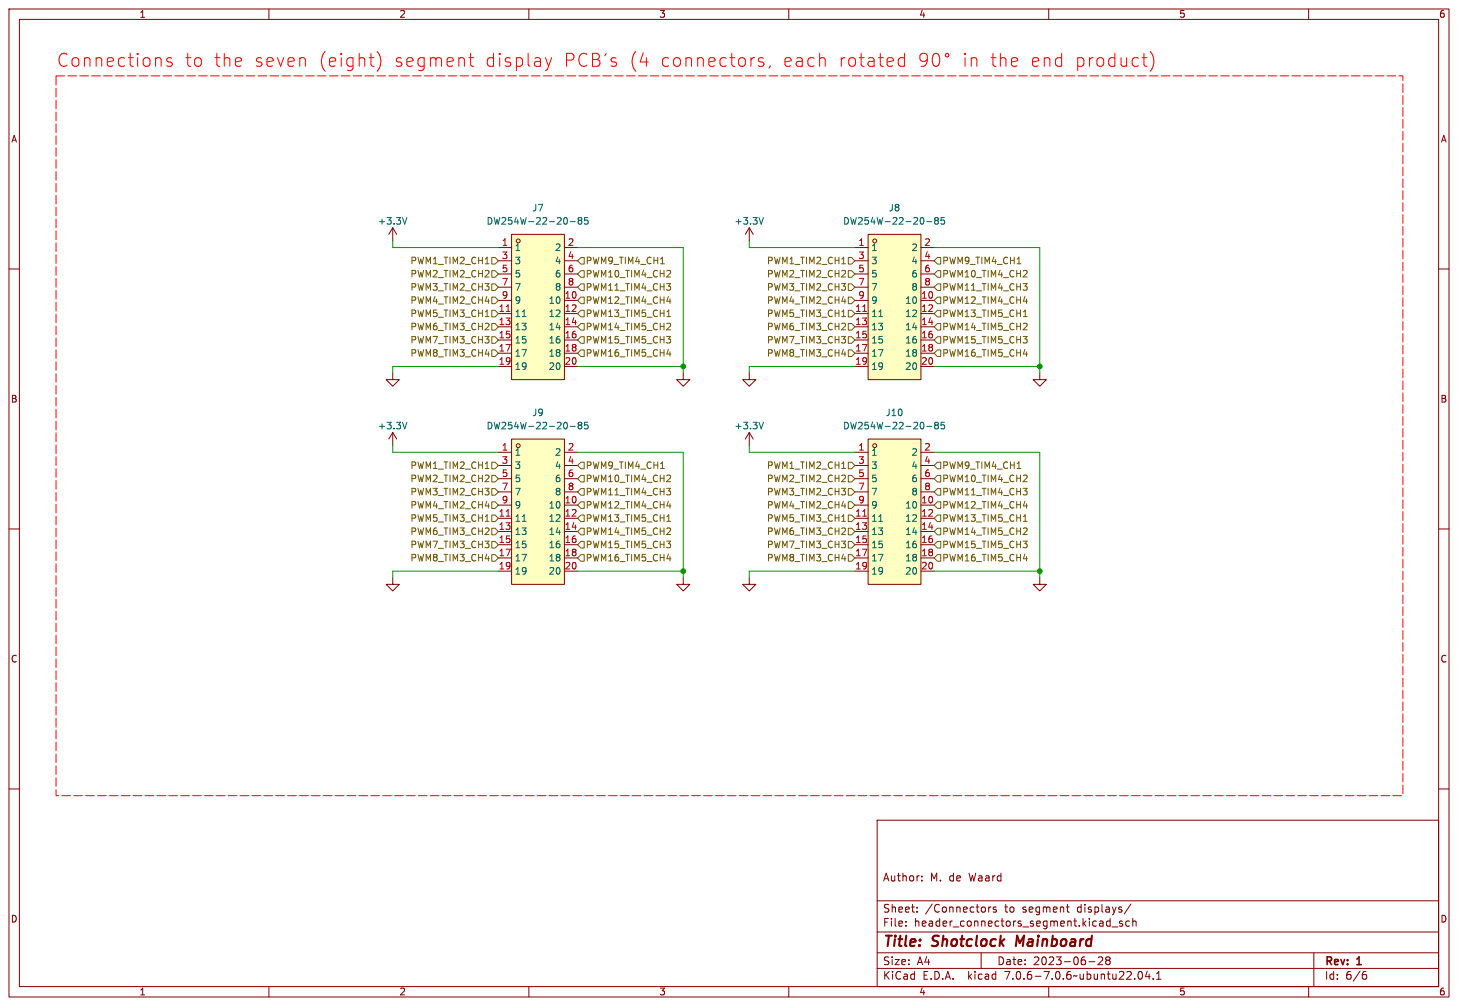
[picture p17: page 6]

Id: 6/6 Title: Shotclock Mainboard

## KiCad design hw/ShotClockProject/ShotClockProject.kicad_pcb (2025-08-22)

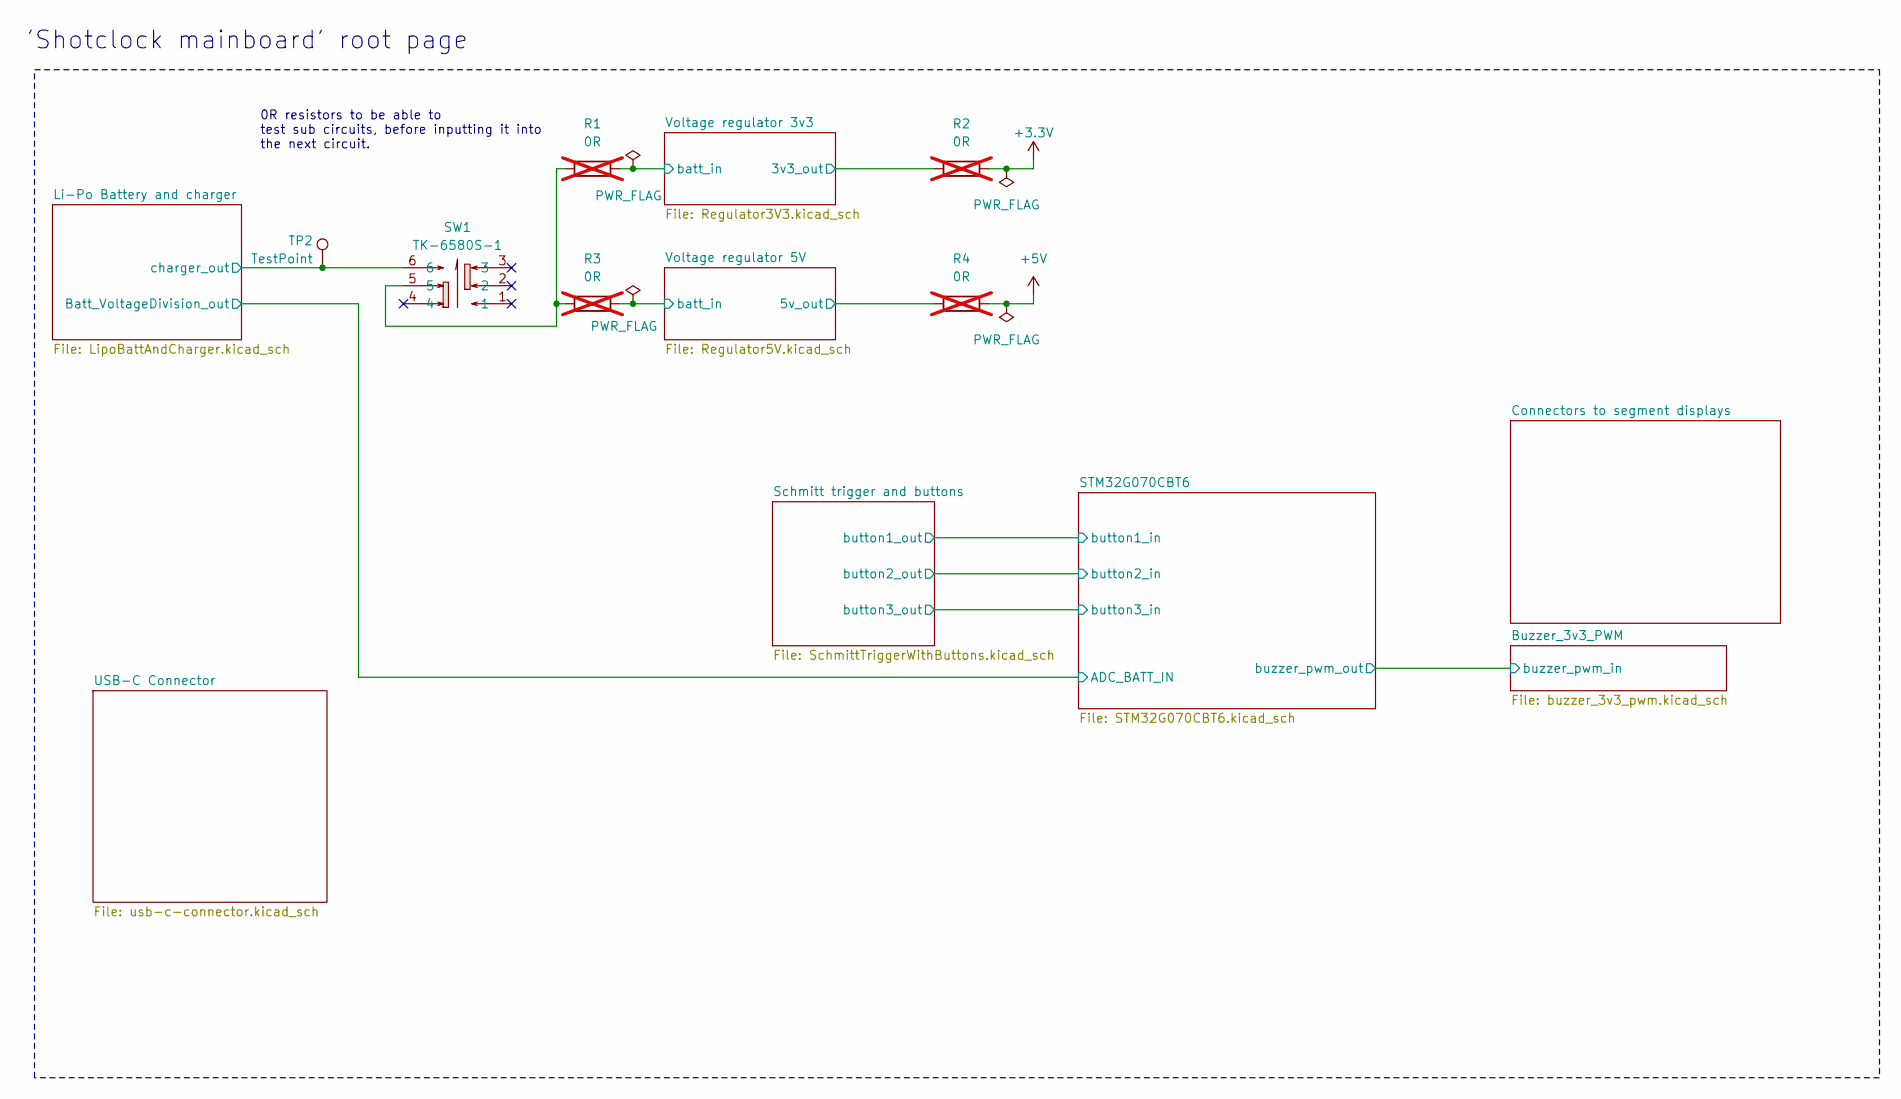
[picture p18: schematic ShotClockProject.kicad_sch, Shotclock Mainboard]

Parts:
R1, R2, R3, R4: 0R; R_0402_1005Metric; LCSC Part C17168; not fitted
SW1: TK-6580S-1; SW-SMD_TK-6580S-1; LCSC Part C528774
TP2: TestPoint; TestPoint_Pad_D1.0mm

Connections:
+3.3V: R2.2; also elsewhere on the board
+5V: R4.2; also elsewhere on the board
/Li-Po Battery and charger/charger_out: SW1.6, TP2.1; also elsewhere on the board
/Voltage regulator 3v3/3v3_out: R2.1; also elsewhere on the board
/Voltage regulator 3v3/batt_in: R1.2; also elsewhere on the board
/Voltage regulator 5V/5v_out: R4.1; also elsewhere on the board
/Voltage regulator 5V/batt_in: R3.2; also elsewhere on the board
unnamed: R1.1, R3.1, SW1.5

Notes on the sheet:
0R resistors to be able to test sub circuits, before inputting it into the next circuit.
'Shotclock mainboard' root page

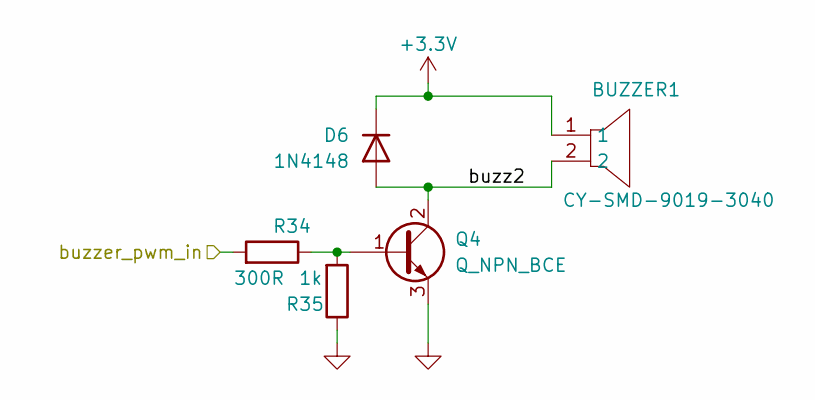
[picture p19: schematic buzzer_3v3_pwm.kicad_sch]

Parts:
BUZZER1: CY-SMD-9019-3040; BUZ-SMD_L9.0-W9.0-P8.00-LS9.3_CY; JLC Part Extended Part
D6: 1N4148; D_SOD-323; LCSC Part C2128
Q4: Q_NPN_BCE; SOT-23; LCSC Part C111113
R34: 300R; R_0402_1005Metric; LCSC Part C25102
R35: 1k; R_0402_1005Metric; LCSC Part C105637

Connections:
+3.3V: BUZZER1.1, D6.1 (K); also elsewhere on the board
/Buzzer_3v3_PWM/buzz2: BUZZER1.2, D6.2 (A), Q4.2 (C)
/Buzzer_3v3_PWM/buzzer_pwm_in: R34.2; also elsewhere on the board
GND: Q4.3 (E), R35.1; also elsewhere on the board
unnamed: Q4.1 (B), R34.1, R35.2

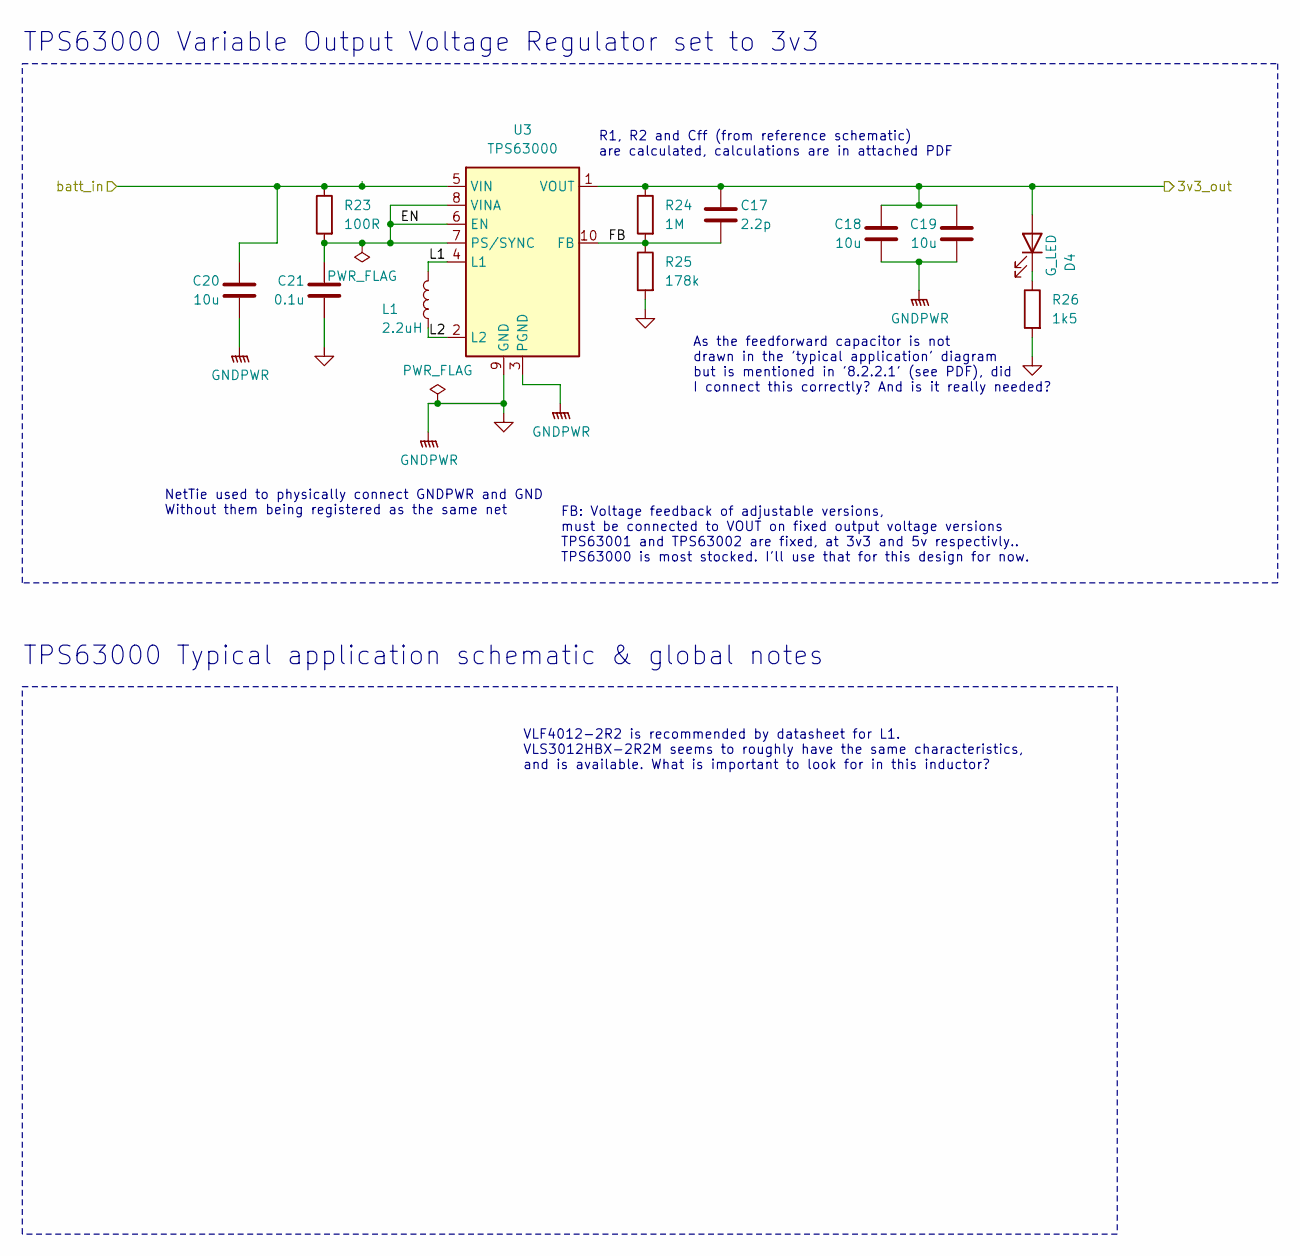
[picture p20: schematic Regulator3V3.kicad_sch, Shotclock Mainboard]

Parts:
C17: 2.2p; C_0402_1005Metric; LCSC Part C1559
C18, C19, C20: 10u; C_0603_1608Metric; LCSC Part C96446
C21: 0.1u; C_0402_1005Metric; LCSC Part C1525
D4: G_LED; LED_0603_1608Metric; LCSC Part C72043
L1: 2.2uH; L_Sunlord_SWPA3012S; LCSC Part C404494
R23: 100R; R_0402_1005Metric; LCSC Part C25076
R24: 1M; R_0402_1005Metric; LCSC Part C144787
R25: 178k; R_0402_1005Metric; LCSC Part C185459
R26: 1k5; R_0402_1005Metric; LCSC Part C25867
U3: TPS63000; Texas_DRC0010J_Altered; LCSC Part C24966

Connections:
/Voltage regulator 3v3/3v3_out: C17.1, C18.1, C19.1, D4.2 (A), R24.1, U3.1 (VOUT); also elsewhere on the board
/Voltage regulator 3v3/EN: C21.1, R23.2, U3.6 (EN), U3.7 (PS/SYNC), U3.8 (VINA)
/Voltage regulator 3v3/FB: C17.2, R24.2, R25.1, U3.10 (FB)
/Voltage regulator 3v3/L1: L1.1, U3.4 (L1)
/Voltage regulator 3v3/L2: L1.2, U3.2 (L2)
/Voltage regulator 3v3/batt_in: C20.1, R23.1, U3.5 (VIN); also elsewhere on the board
GND: C18.2, C19.2, C20.2, C21.2, R25.2, R26.2, U3.3 (PGND), U3.9 (GND), U3.11 (PGND); also elsewhere on the board
unnamed: D4.1 (K), R26.1

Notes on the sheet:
As the feedforward capacitor is not drawn in the 'typical application' diagram but is mentioned in '8.2.2.1' (see PDF), did I connect this correctly? And is it really needed?
NetTie used to physically connect GNDPWR and GND Without them being registered as the same net
R1, R2 and Cff (from reference schematic) are calculated, calculations are in attached PDF
FB: Voltage feedback of adjustable versions, must be connected to VOUT on fixed output voltage versions TPS63001 and TPS63002 are fixed, at 3v3 and 5v respectivly.. TPS63000 is most stocked. I'll use that for this design for now.
TPS63000 Variable Output Voltage Regulator set to 3v3
VLF4012-2R2 is recommended by datasheet for L1. VLS3012HBX-2R2M seems to roughly have the same characteristics, and is available. What is important to look for in this inductor?
TPS63000 Typical application schematic & global notes

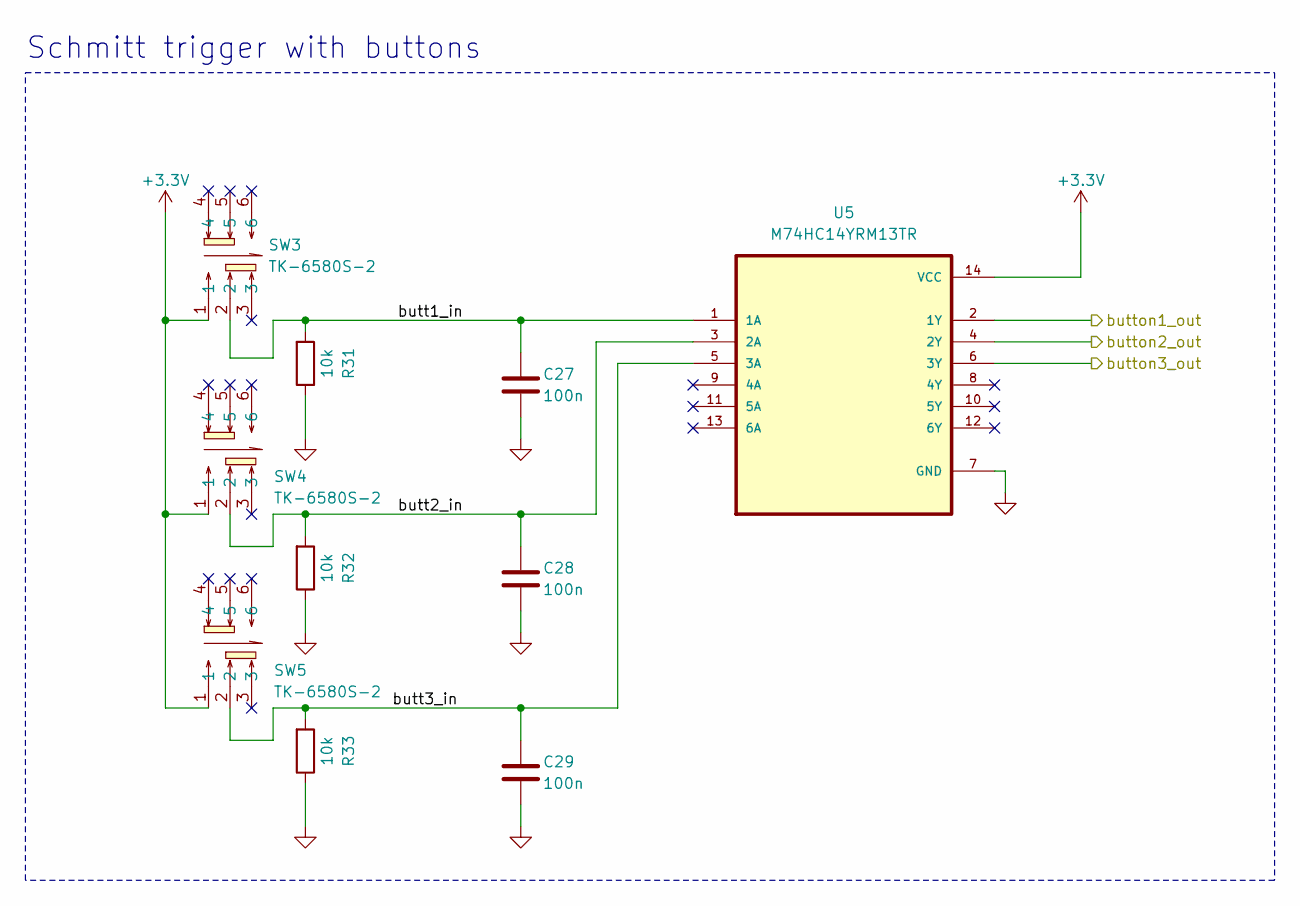
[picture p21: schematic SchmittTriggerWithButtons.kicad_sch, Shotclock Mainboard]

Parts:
C27, C28, C29: 100n; C_0402_1005Metric; LCSC Part C1525
R31, R32, R33: 10k; R_0402_1005Metric; LCSC Part C25744
SW3, SW4, SW5: TK-6580S-2; SW-SMD_TK-6580S-2; LCSC Part C528775
U5: M74HC14YRM13TR; SOIC-14_3.9x8.7mm_P1.27mm; LCSC Part C157450

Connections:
+3.3V: SW3.1, SW4.1, SW5.1, U5.14 (VCC); also elsewhere on the board
/STM32G070CBT6/button1_in: U5.2 (1Y); also elsewhere on the board
/STM32G070CBT6/button2_in: U5.4 (2Y); also elsewhere on the board
/STM32G070CBT6/button3_in: U5.6 (3Y); also elsewhere on the board
/Schmitt trigger and buttons/butt1_in: C27.1, R31.2, SW3.2, U5.1 (1A)
/Schmitt trigger and buttons/butt2_in: C28.1, R32.2, SW4.2, U5.3 (2A)
/Schmitt trigger and buttons/butt3_in: C29.1, R33.2, SW5.2, U5.5 (3A)
GND: C27.2, C28.2, C29.2, R31.1, R32.1, R33.1, U5.7 (GND); also elsewhere on the board

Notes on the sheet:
Schmitt trigger with buttons

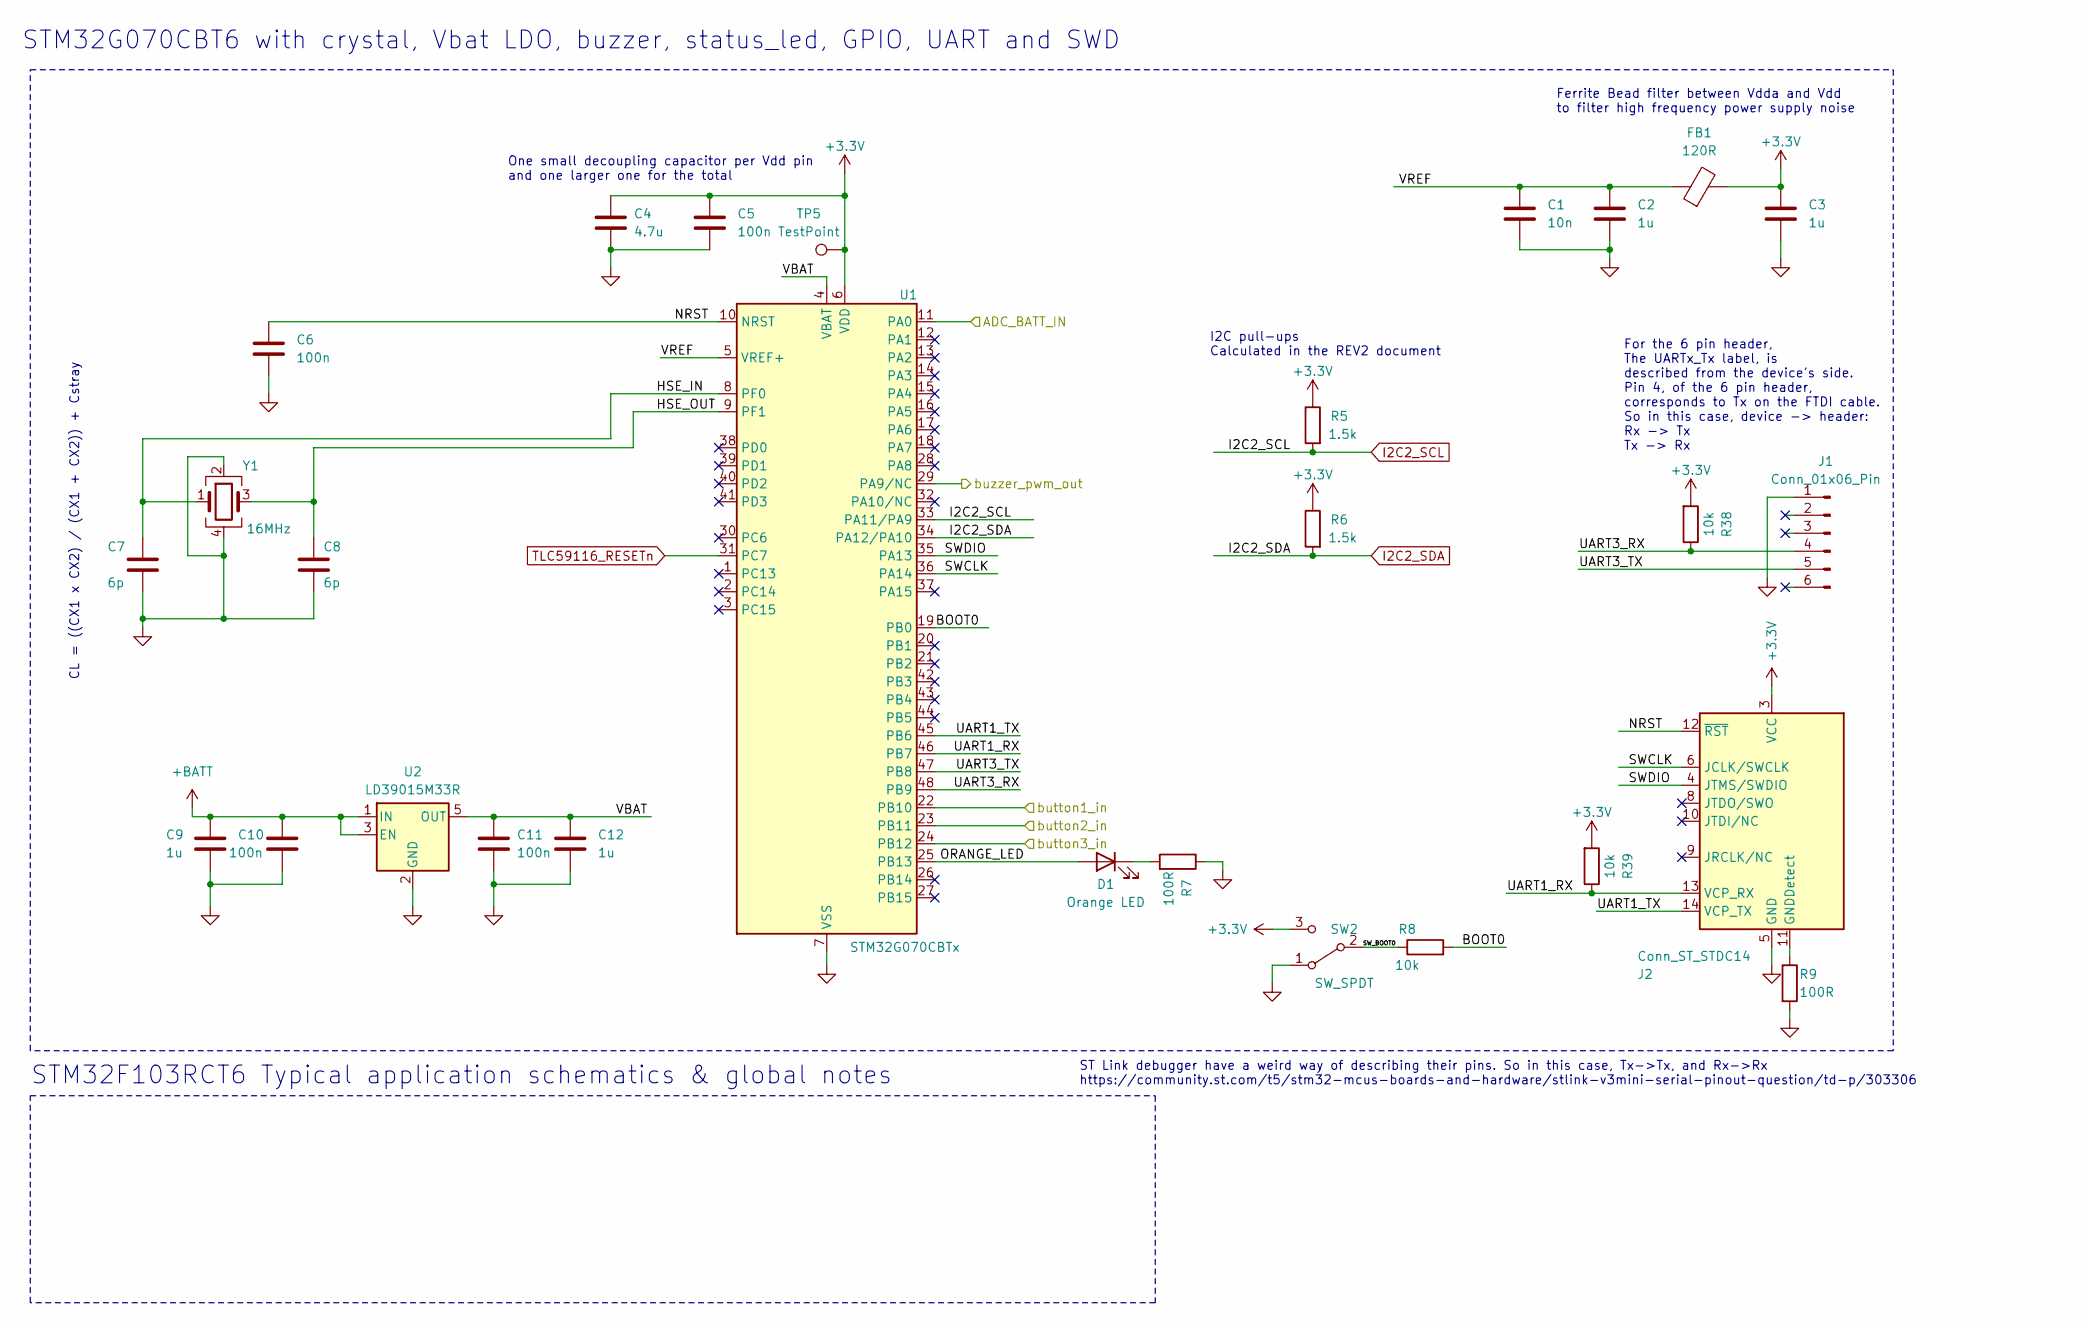
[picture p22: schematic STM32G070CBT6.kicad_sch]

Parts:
C1: 10n; C_0402_1005Metric; LCSC Part C15195
C2, C3, C9, C12: 1u; C_0402_1005Metric; LCSC Part C52923
C4: 4.7u; C_0402_1005Metric; LCSC Part C23733
C5, C6, C10, C11: 100n; C_0402_1005Metric; LCSC Part C1525
C7, C8: 6p; C_0402_1005Metric; LCSC Part C1575
D1: Orange LED; LED_0603_1608Metric; LCSC Part C264451
FB1: 120R; L_0603_1608Metric; LCSC Part C127301
J1: Conn_01x06_Pin; PinHeader_1x06_P2.54mm_Horizontal; LCSC Part C56816
J2: Conn_ST_STDC14; PinHeader_2x07_P1.27mm_Vertical_SMD; LCSC Part C3975190
R5, R6: 1.5k; R_0402_1005Metric; LCSC Part C25867
R7, R9: 100R; R_0402_1005Metric; LCSC Part C25076
R8, R38, R39: 10k; R_0402_1005Metric; LCSC Part C25744
SW2: SW_SPDT; SW_SPDT_PCM12_Upwards; LCSC Part C500057
TP5: TestPoint; TestPoint_Pad_D1.0mm
U1: STM32G070CBTx; LQFP-48_7x7mm_P0.5mm; LCSC Part C529338
U2: LD39015M33R; SOT-23-5; LCSC Part C2798212
Y1: 16MHz; Crystal_SMD_3225-4Pin_3.2x2.5mm; LCSC Part C112972

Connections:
+3.3V: C3.1, C4.1, C5.1, FB1.2, J2.3 (VCC), R5.1, R6.1, R38.2, R39.2, SW2.3 (C), TP5.1, U1.6 (VDD); also elsewhere on the board
+BATT: C9.1, C10.1, U2.1 (IN), U2.3 (EN); also elsewhere on the board
/Buzzer_3v3_PWM/buzzer_pwm_in: U1.29 (PA9/NC); also elsewhere on the board
/Li-Po Battery and charger/Batt_VoltageDivision_out: U1.11 (PA0); also elsewhere on the board
/STM32G070CBT6/BOOT0: R8.2, U1.19 (PB0)
/STM32G070CBT6/HSE_IN: C7.1, U1.8 (PF0), Y1.1
/STM32G070CBT6/HSE_OUT: C8.1, U1.9 (PF1), Y1.3
/STM32G070CBT6/NRST: C6.1, J2.12 (~RST), U1.10 (NRST)
/STM32G070CBT6/ORANGE_LED: D1.2 (A), U1.25 (PB13)
/STM32G070CBT6/SWCLK: J2.6 (JCLK/SWCLK), U1.36 (PA14)
/STM32G070CBT6/SWDIO: J2.4 (JTMS/SWDIO), U1.35 (PA13)
/STM32G070CBT6/SW_BOOT0: R8.1, SW2.2 (B)
/STM32G070CBT6/UART1_RX: J2.13 (VCP_RX), R39.1, U1.46 (PB7)
/STM32G070CBT6/UART1_TX: J2.14 (VCP_TX), U1.45 (PB6)
/STM32G070CBT6/UART3_RX: J1.4, R38.1, U1.48 (PB9)
/STM32G070CBT6/UART3_TX: J1.5, U1.47 (PB8)
/STM32G070CBT6/VBAT: C11.1, C12.1, U1.4 (VBAT), U2.5 (OUT)
/STM32G070CBT6/VREF: C1.1, C2.1, FB1.1, U1.5 (VREF+)
/STM32G070CBT6/button1_in: U1.22 (PB10); also elsewhere on the board
/STM32G070CBT6/button2_in: U1.23 (PB11); also elsewhere on the board
/STM32G070CBT6/button3_in: U1.24 (PB12); also elsewhere on the board
GND: C1.2, C2.2, C3.2, C4.2, C5.2, C6.2, C7.2, C8.2, C9.2, C10.2, C11.2, C12.2, J1.1, J2.5 (GND), J2.7 (GND), R7.1, R9.2, SW2.1 (A), U1.7 (VSS), U2.2 (GND), Y1.2, Y1.4; also elsewhere on the board
I2C2_SCL: R5.2, U1.33 (PA11/PA9); also elsewhere on the board
I2C2_SDA: R6.2, U1.34 (PA12/PA10); also elsewhere on the board
unnamed: D1.1 (K), R7.2
unnamed: J2.11 (GNDDetect), R9.1
TLC59116_RESETn: U1.31 (PC7); also elsewhere on the board

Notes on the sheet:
STM32F103RCT6 Typical application schematics & global notes
ST Link debugger have a weird way of describing their pins. So in this case, Tx->Tx, and Rx->Rx https://community.st.com/t5/stm32-mcus-boards-and-hardware/stlink-v3mini-serial-pinout-question/td-p/303306
For the 6 pin header, The UARTx_Tx label, is described from the device's side. Pin 4, of the 6 pin header, corresponds to Tx on the FTDI cable. So in this case, device -> header: Rx -> Tx Tx -> Rx
One small decoupling capacitor per Vdd pin and one larger one for the total
Ferrite Bead filter between Vdda and Vdd to filter high frequency power supply noise
I2C pull-ups Calculated in the REV2 document
STM32G070CBT6 with crystal, Vbat LDO, buzzer, status_led, GPIO, UART and SWD
CL = ((CX1 x CX2) / (CX1 + CX2)) + Cstray

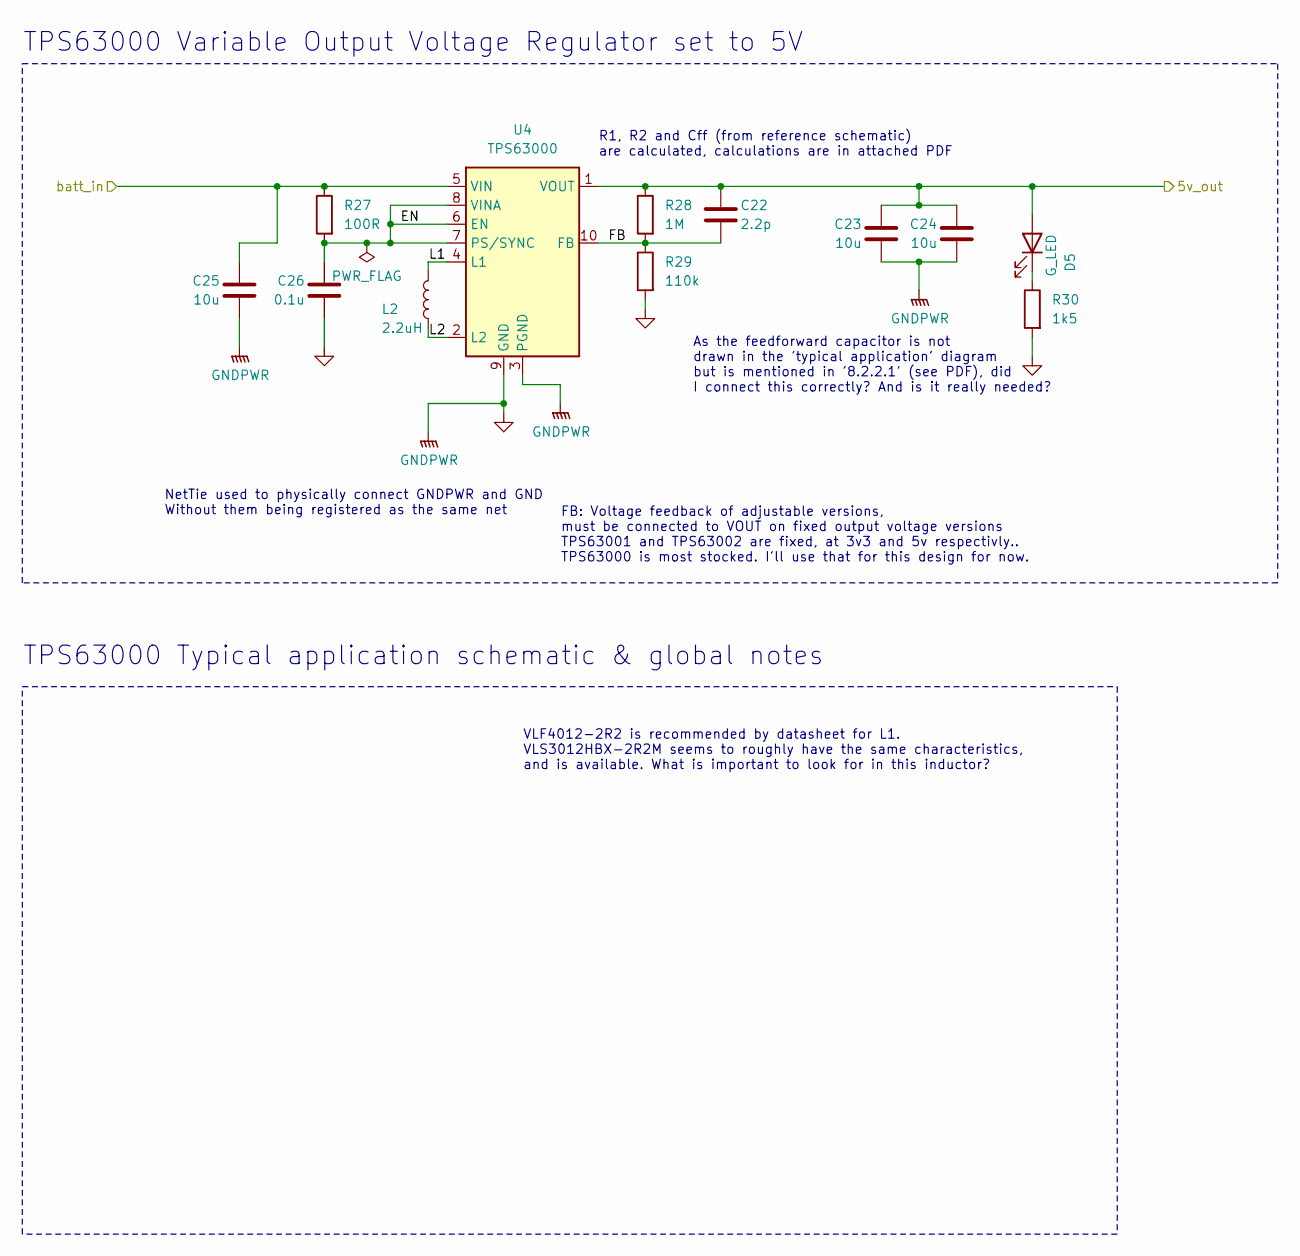
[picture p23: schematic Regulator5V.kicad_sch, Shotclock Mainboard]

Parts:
C22: 2.2p; C_0402_1005Metric; LCSC Part C1559
C23, C24, C25: 10u; C_0603_1608Metric; LCSC Part C96446
C26: 0.1u; C_0402_1005Metric; LCSC Part C1525
D5: G_LED; LED_0603_1608Metric; LCSC Part C72043
L2: 2.2uH; L_Sunlord_SWPA3012S; LCSC Part C404494
R27: 100R; R_0402_1005Metric; LCSC Part C25076
R28: 1M; R_0402_1005Metric; LCSC Part C144787
R29: 110k; R_0402_1005Metric; LCSC Part C25745
R30: 1k5; R_0402_1005Metric; LCSC Part C25867
U4: TPS63000; Texas_DRC0010J_Altered; LCSC Part C24966

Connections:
/Voltage regulator 5V/5v_out: C22.1, C23.1, C24.1, D5.2 (A), R28.1, U4.1 (VOUT); also elsewhere on the board
/Voltage regulator 5V/EN: C26.1, R27.2, U4.6 (EN), U4.7 (PS/SYNC), U4.8 (VINA)
/Voltage regulator 5V/FB: C22.2, R28.2, R29.1, U4.10 (FB)
/Voltage regulator 5V/L1: L2.1, U4.4 (L1)
/Voltage regulator 5V/L2: L2.2, U4.2 (L2)
/Voltage regulator 5V/batt_in: C25.1, R27.1, U4.5 (VIN); also elsewhere on the board
GND: C23.2, C24.2, C25.2, C26.2, R29.2, R30.2, U4.3 (PGND), U4.9 (GND), U4.11 (PGND); also elsewhere on the board
unnamed: D5.1 (K), R30.1

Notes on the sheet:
As the feedforward capacitor is not drawn in the 'typical application' diagram but is mentioned in '8.2.2.1' (see PDF), did I connect this correctly? And is it really needed?
NetTie used to physically connect GNDPWR and GND Without them being registered as the same net
R1, R2 and Cff (from reference schematic) are calculated, calculations are in attached PDF
FB: Voltage feedback of adjustable versions, must be connected to VOUT on fixed output voltage versions TPS63001 and TPS63002 are fixed, at 3v3 and 5v respectivly.. TPS63000 is most stocked. I'll use that for this design for now.
TPS63000 Variable Output Voltage Regulator set to 5V
VLF4012-2R2 is recommended by datasheet for L1. VLS3012HBX-2R2M seems to roughly have the same characteristics, and is available. What is important to look for in this inductor?
TPS63000 Typical application schematic & global notes

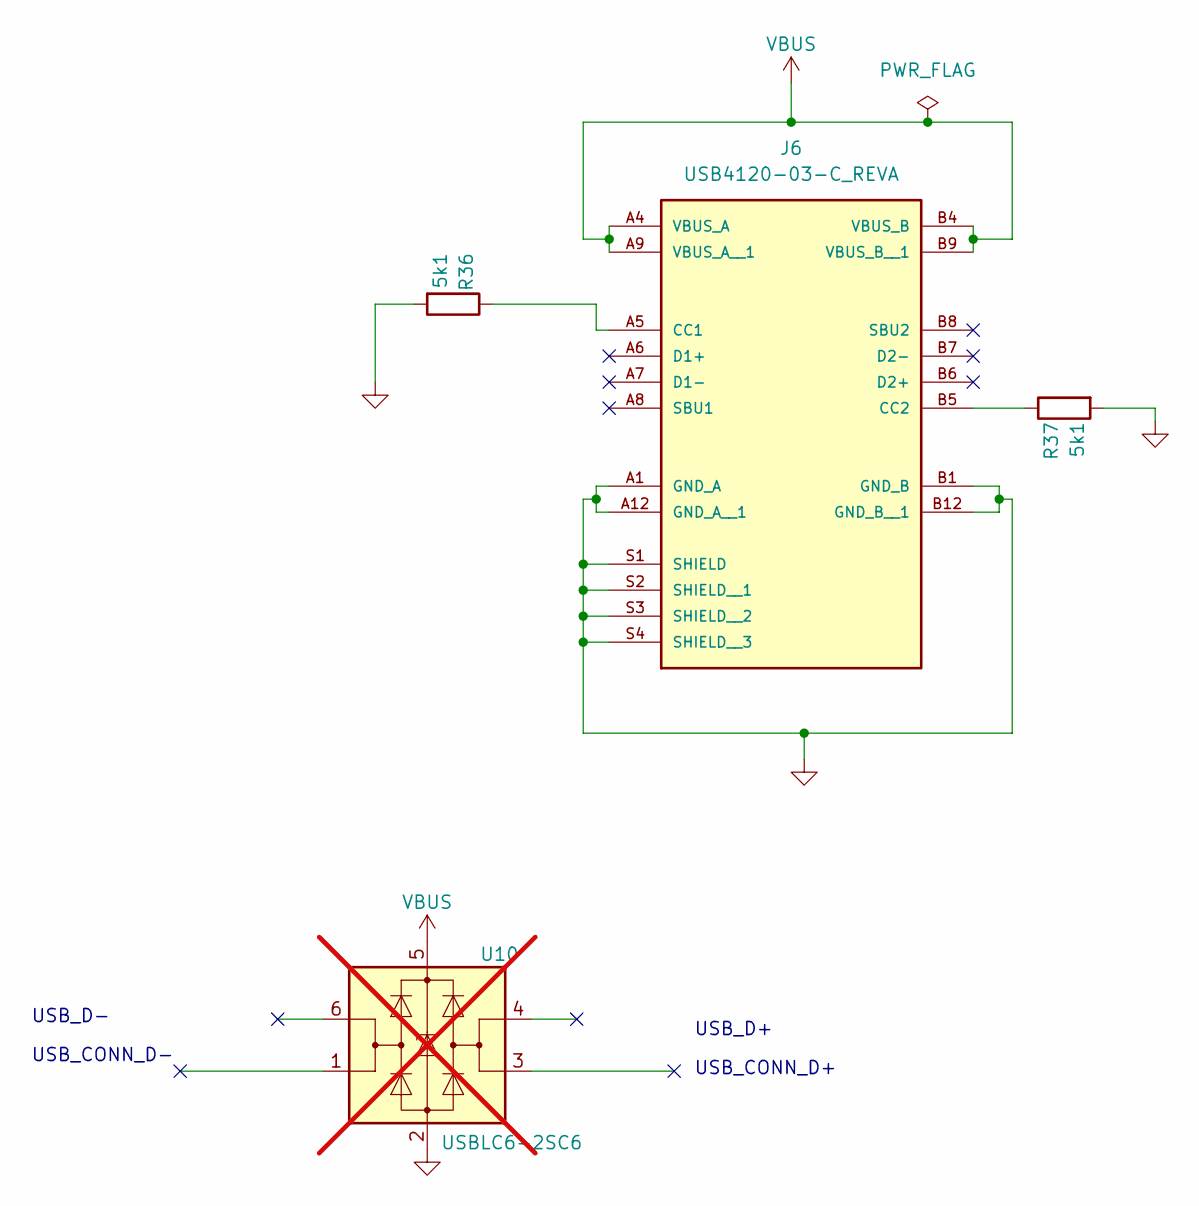
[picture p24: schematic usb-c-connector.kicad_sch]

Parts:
J6: USB4120-03-C_REVA; GCT_USB4120-03-C_REVA_With3DModel; PARTREV A; LCSC Part C5187468
R36, R37: 5k1; R_0402_1005Metric; LCSC Part C25905
U10: USBLC6-2SC6; SOT-23-6; LCSC Part C7519; not fitted

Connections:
GND: J6.A1 (GND_A), J6.A12 (GND_A__1), J6.B1 (GND_B), J6.B12 (GND_B__1), J6.S1 (SHIELD), J6.S2 (SHIELD__1), J6.S3 (SHIELD__2), J6.S4 (SHIELD__3), R36.2, R37.2, U10.2 (GND); also elsewhere on the board
unnamed: J6.A5 (CC1), R36.1
unnamed: J6.B5 (CC2), R37.1
VBUS: J6.A4 (VBUS_A), J6.A9 (VBUS_A__1), J6.B4 (VBUS_B), J6.B9 (VBUS_B__1), U10.5 (VBUS); also elsewhere on the board

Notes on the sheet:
USB_CONN_D-
USB_D-
USB_D+
USB_CONN_D+

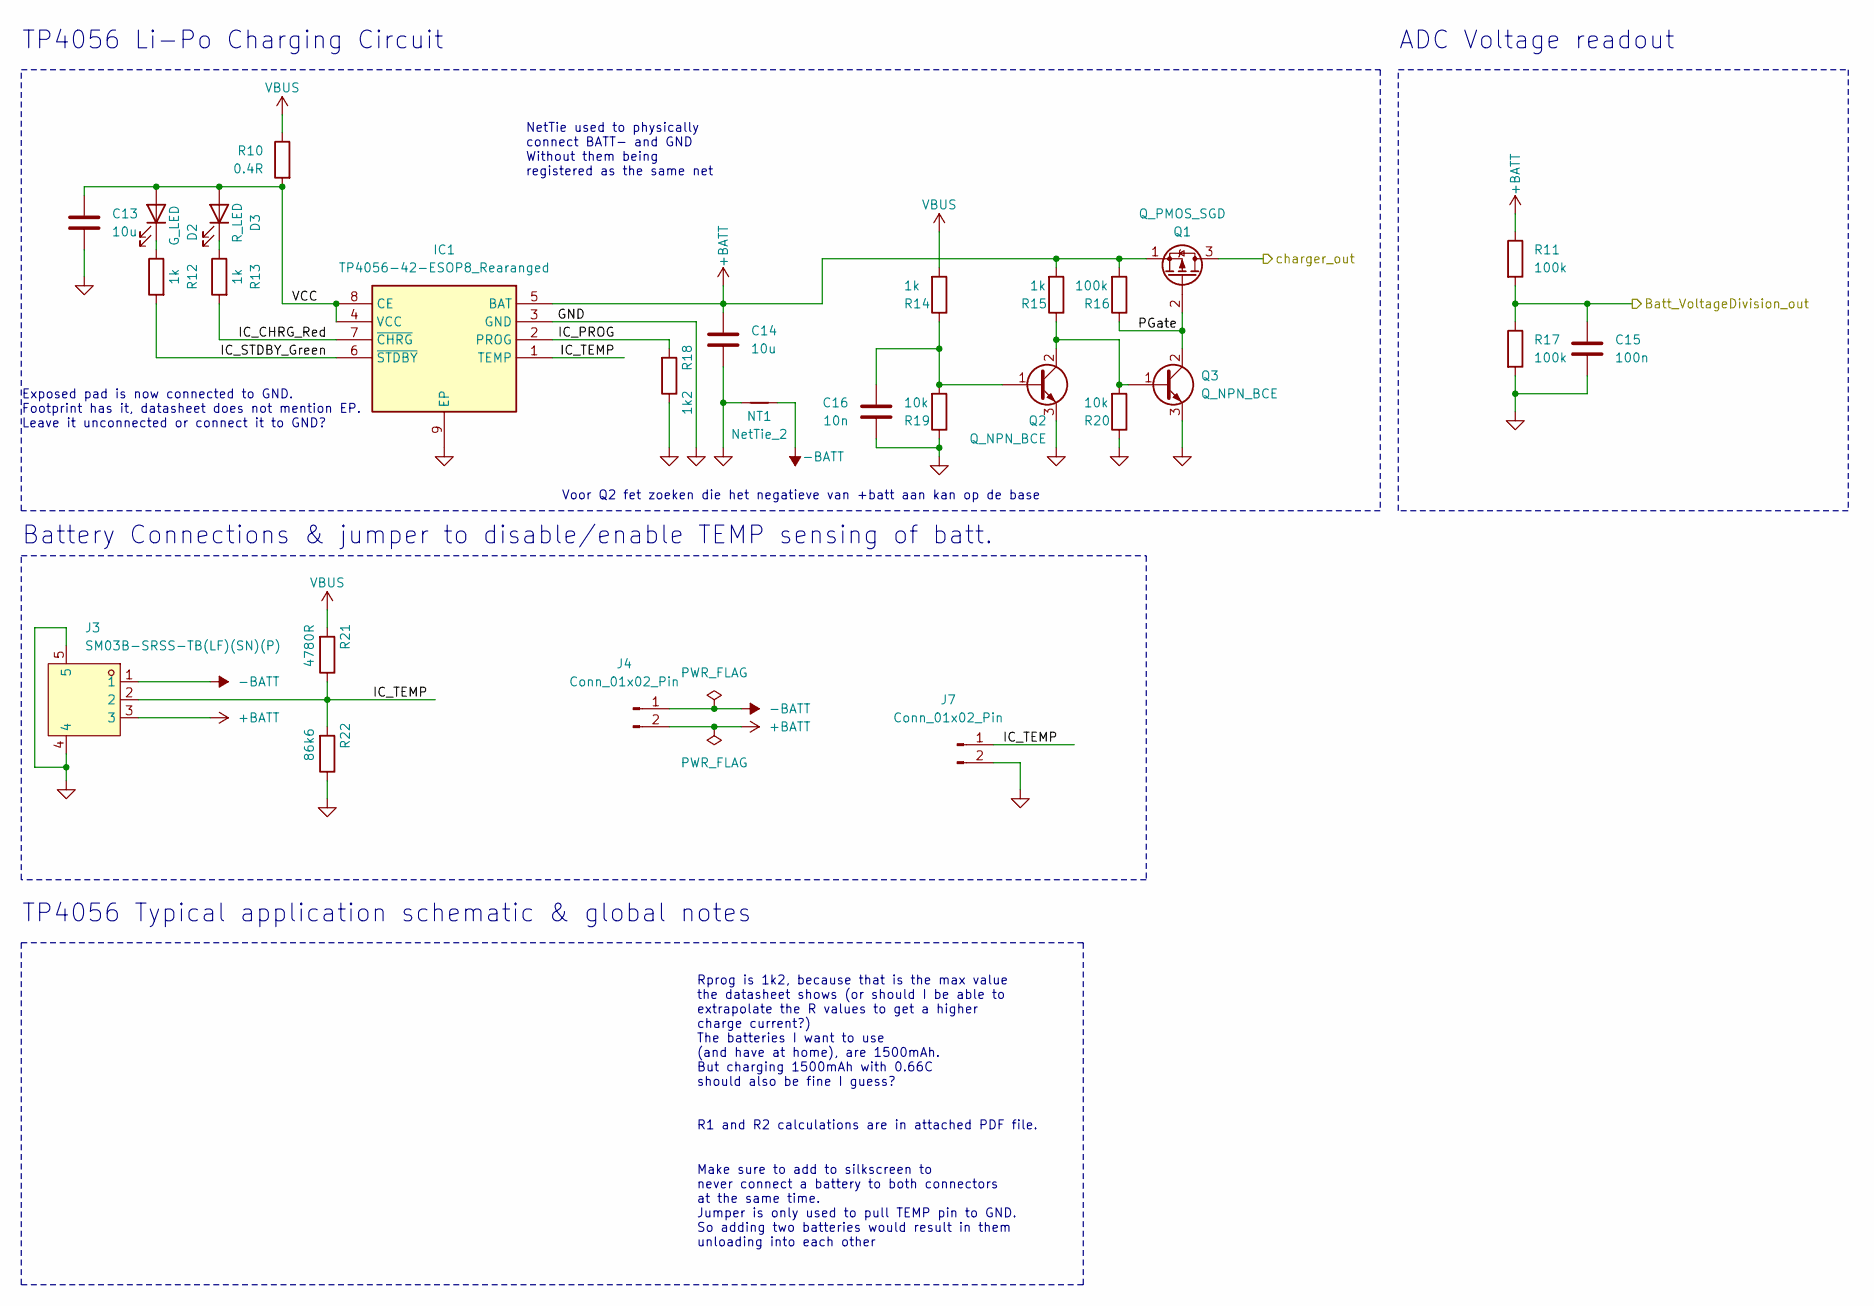
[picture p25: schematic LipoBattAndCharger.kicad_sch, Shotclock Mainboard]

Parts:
C13, C14: 10u; C_0402_1005Metric; LCSC Part C15525
C15: 100n; C_0402_1005Metric; LCSC Part C1525
C16: 10n; C_0402_1005Metric; LCSC Part C15195
D2: G_LED; LED_0603_1608Metric; LCSC Part C72043
D3: R_LED; LED_0603_1608Metric; LCSC Part C128250
IC1: TP4056-42-ESOP8_Rearanged; Texas_HSOP-8-1EP_3.9x4.9mm_P1.27mm; Manufacturer_Part_Number TP4056-42-ESOP8; LCSC Part C725790
J3: SM03B-SRSS-TB(LF)(SN)(P); CONN-SMD_SM03B-SRSS-TB-LF-SN-P; JLC Part Extended Part
J4, J7: Conn_01x02_Pin; PinHeader_1x02_P2.54mm_Horizontal; LCSC Part C492410
NT1: NetTie_2; NetTie-2_SMD_Pad0.5mm
Q1: Q_PMOS_SGD; TO-263-2; LCSC Part C33903
Q2, Q3: Q_NPN_BCE; SOT-23; LCSC Part C111113
R10: 0.4R; R_0402_1005Metric; LCSC Part C27147
R11, R16, R17: 100k; R_0402_1005Metric; LCSC Part C25741
R12, R13, R14, R15: 1k; R_0402_1005Metric; LCSC Part C105637
R18: 1k2; R_0402_1005Metric; LCSC Part C25862
R19, R20: 10k; R_0402_1005Metric; LCSC Part C25744
R21: 4780R; R_0402_1005Metric; LCSC Part C25900
R22: 86k6; R_0402_1005Metric; LCSC Part C852935

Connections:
+BATT: C14.1, IC1.5 (BAT), J3.3, J4.2, Q1.1 (S), R11.1, R15.2, R16.2; also elsewhere on the board
-BATT: J3.1, J4.1, NT1.2
/Li-Po Battery and charger/Batt_VoltageDivision_out: C15.1, R11.2, R17.1; also elsewhere on the board
/Li-Po Battery and charger/IC_CHRG_Red: IC1.7 (~CHRG), R13.2
/Li-Po Battery and charger/IC_PROG: IC1.2 (PROG), R18.2
/Li-Po Battery and charger/IC_STDBY_Green: IC1.6 (~STDBY), R12.2
/Li-Po Battery and charger/IC_TEMP: IC1.1 (TEMP), J3.2, J7.1, R21.1, R22.2
/Li-Po Battery and charger/PGate: Q1.2 (G), Q3.2 (C), R16.1
/Li-Po Battery and charger/VCC: C13.1, D2.2 (A), D3.2 (A), IC1.4 (VCC), IC1.8 (CE), R10.2
/Li-Po Battery and charger/charger_out: Q1.3 (D); also elsewhere on the board
GND: C13.2, C14.2, C15.2, C16.2, IC1.3 (GND), IC1.9 (EP), J3.4, J3.5, J7.2, NT1.1, Q2.3 (E), Q3.3 (E), R17.2, R18.1, R19.1, R20.1, R22.1; also elsewhere on the board
unnamed: D2.1 (K), R12.1
unnamed: D3.1 (K), R13.1
unnamed: C16.1, Q2.1 (B), R14.1, R19.2
unnamed: Q2.2 (C), Q3.1 (B), R15.1, R20.2
VBUS: R10.1, R14.2, R21.2; also elsewhere on the board

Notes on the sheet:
Rprog is 1k2, because that is the max value the datasheet shows (or should I be able to extrapolate the R values to get a higher charge current?) The batteries I want to use (and have at home), are 1500mAh. But charging 1500mAh with 0.66C should also be fine I guess? R1 and R2 calculations are in a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
TP4056 Li-Po Charging Circuit
TP4056 Typical application schematic & global notes
ADC Voltage readout
Battery Connections & jumper to disable/enable TEMP sensing of batt.
Make sure to add to silkscreen to never connect a battery to both connectors at the same time. Jumper is only used to pull TEMP pin to GND. So adding two batteries would result in them unloading into each other
Voor Q2 fet zoeken die het negatieve van +batt aan kan op de base
NetTie used to physically connect BATT- and GND Without them being registered as the same net
Exposed pad is now connected to GND. Footprint has it, datasheet does not mention EP. Leave it unconnected or connect it to GND?

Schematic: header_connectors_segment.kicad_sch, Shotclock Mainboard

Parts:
U6, U7, U8, U9: S6B-PH-K-S-(LF)(SN); CONN-TH_6P-P2.00_S6B-PH-K-S-LF-SN; LCSC Part C157920

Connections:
+3.3V: U6.2, U7.2, U8.2, U9.2; also elsewhere on the board
+5V: U6.3, U7.3, U8.3, U9.3; also elsewhere on the board
GND: U6.6, U7.6, U8.6, U9.6; also elsewhere on the board
I2C2_SCL: U6.4, U7.4, U8.4, U9.4; also elsewhere on the board
I2C2_SDA: U6.5, U7.5, U8.5, U9.5; also elsewhere on the board
TLC59116_RESETn: U6.1, U7.1, U8.1, U9.1; also elsewhere on the board

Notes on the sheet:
Connections to the seven (eight) segment display PCB's (4 connectors, each rotated 90° in the end product)

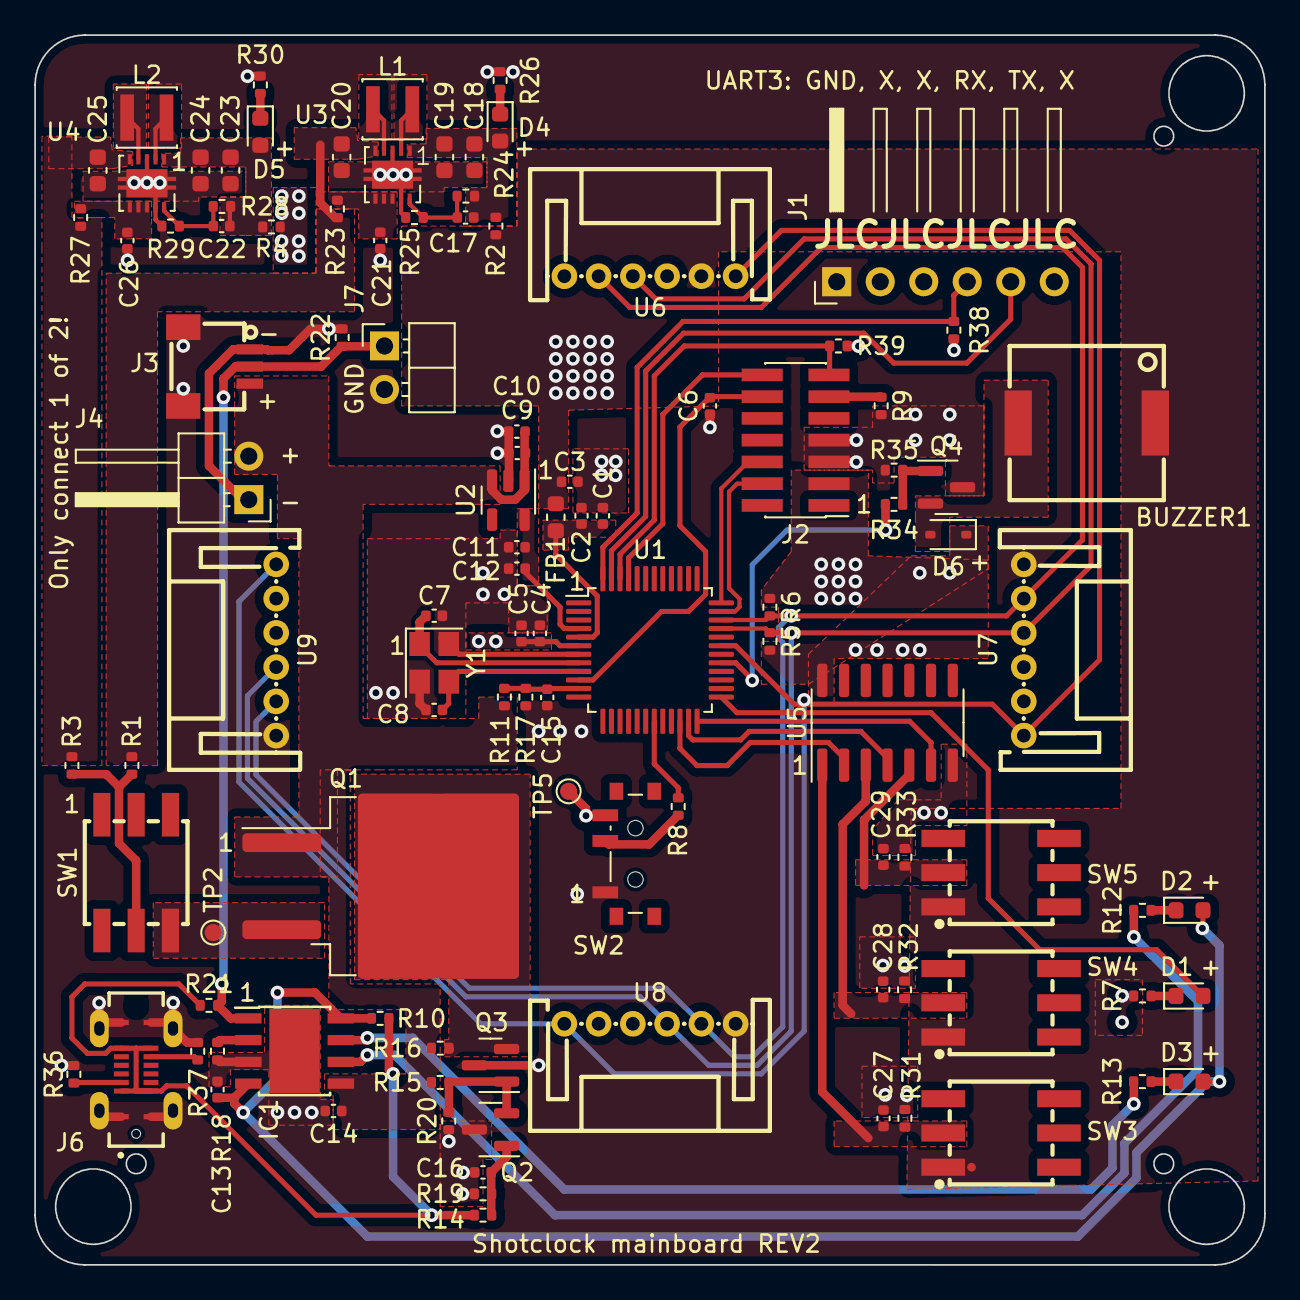
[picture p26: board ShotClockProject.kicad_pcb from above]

Board: 4 copper layers, 71.8 x 71.8 mm, 107 parts (0 on the bottom side), 63 nets.

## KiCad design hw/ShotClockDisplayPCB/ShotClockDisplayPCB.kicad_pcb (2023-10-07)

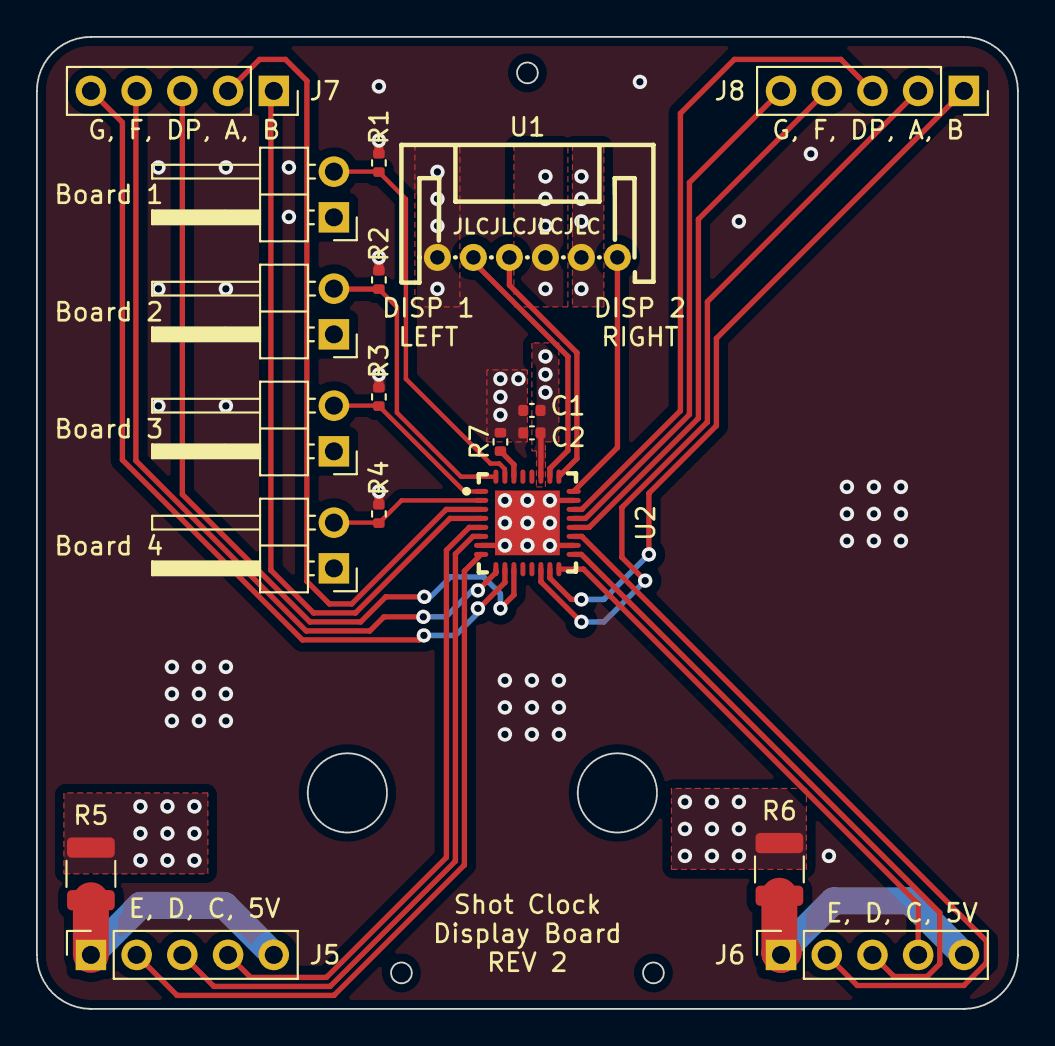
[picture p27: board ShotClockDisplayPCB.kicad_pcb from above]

Board: 4 copper layers, 54.5 x 54.0 mm, 19 parts (0 on the bottom side), 29 nets.

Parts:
C1: 100p; C_0402_1005Metric
C2: 10u; C_0402_1005Metric
J1, J2, J3, J4: Conn_01x02_Pin; PinHeader_1x02_P2.54mm_Horizontal
J5, J6, J7, J8: Conn_01x05_Socket; PinSocket_1x05_P2.54mm_Vertical
R1, R2, R3, R4: 10k; R_0402_1005Metric
R5, R6: 100r; R_1210_3225Metric
R7: 1k; R_0402_1005Metric
U1: S6B-PH-K-S-(LF)(SN); CONN-TH_6P-P2.00_S6B-PH-K-S-LF-SN
U2: TLC59116IRHBR; PG-VQFN-32_L5.0-W5.0-P0.50-BL-EP3.6

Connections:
+3.3V: C1.1, C2.1, J1.1, J2.1, J3.1, J4.1, U1.2, U2.27 (VCC)
+5V: R5.1, R6.1, U1.3
/I2C PWM IO Expander/A0: J1.2, R1.1, U2.31 (A0)
/I2C PWM IO Expander/A1: J2.2, R2.1, U2.32 (A1)
/I2C PWM IO Expander/A2: J3.2, R3.1, U2.1 (A2)
/I2C PWM IO Expander/A3: J4.2, R4.1, U2.2 (A3)
/I2C PWM IO Expander/I2C1_SCL: U1.4, U2.25 (SCL)
/I2C PWM IO Expander/I2C1_SDA: U1.5, U2.26 (SDA)
/I2C PWM IO Expander/REXT: R7.1, U2.30 (REXT)
/I2C PWM IO Expander/TLC59116_RESETn: U1.1, U2.24 (RESET)
/Segment Display Connectors/5V_CONN1: J5.1, J5.5, R5.2
/Segment Display Connectors/5V_CONN2: J6.1, J6.5, R6.2
GND: C1.2, C2.2, R1.2, R2.2, R3.2, R4.2, R7.2, U1.6, U2.7 (GND), U2.18 (GND), U2.23 (GND), U2.33 (ep)
SEG1_A: J7.2, U2.3 (~OUT0)
SEG1_B: J7.1, U2.4 (~OUT1)
SEG1_C: J5.4, U2.5 (~OUT2)
SEG1_D: J5.3, U2.6 (~OUT3)
SEG1_DP: J7.3, U2.11 (~OUT7)
SEG1_E: J5.2, U2.8 (~OUT4)
SEG1_F: J7.4, U2.9 (~OUT5)
SEG1_G: J7.5, U2.10 (~OUT6)
SEG2_A: J8.2, U2.14 (~OUT8)
SEG2_B: J8.1, U2.15 (~OUT9)
SEG2_C: J6.4, U2.16 (~OUT10)
SEG2_D: J6.3, U2.17 (~OUT11)
SEG2_DP: J8.3, U2.22 (~OUT15)
SEG2_E: J6.2, U2.19 (~OUT12)
SEG2_F: J8.4, U2.20 (~OUT13)
SEG2_G: J8.5, U2.21 (~OUT14)

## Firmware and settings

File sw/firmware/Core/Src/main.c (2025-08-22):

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
/* Includes ------------------------------------------------------------------*/
#include "main.h"
#include "adc.h"
#include "i2c.h"
#include "tim.h"
#include "usart.h"
#include "gpio.h"

/* USER CODE BEGIN Includes */
#include "cli_setup.h"
#include "TLC59116.h"
#include "segment_display.h"
/* USER CODE END Includes */

/* USER CODE BEGIN PTD */
void HAL_GPIO_EXTI_Falling_Callback(uint16_t GPIO_Pin);
/* USER CODE END PTD */


/* USER CODE BEGIN PV */
volatile int number = 99; // Initial number

/* USER CODE END PV */

void SystemClock_Config(void);
/**
  * @brief  The application entry point.
  * @retval int
  */
int main(void)
{

  /* MCU Configuration--------------------------------------------------------*/

  /* Reset of all peripherals, Initializes the Flash interface and the Systick. */
  HAL_Init();

  /* Configure the system clock */
  SystemClock_Config();

  /* Initialize all configured peripherals */
  MX_GPIO_Init();
  MX_ADC1_Init();
  MX_USART1_UART_Init();
  MX_TIM1_Init();
  MX_I2C2_Init();
  MX_USART3_UART_Init();
  MX_TIM6_Init();
  /* USER CODE BEGIN 2 */

  setupCli();
  // I2C_Scan();
  TLC59116_Init();
  // Start the timer

  // int32_t CH2_DC = 0;

  // int delay_time = 50;
  //uint8_t TX_Buffer [] = "C" ;
  /* USER CODE END 2 */

  /* Infinite loop */
  /* USER CODE BEGIN WHILE */
  while (1)
  {
    /* USER CODE END WHILE */

    /* USER CODE BEGIN 3 */
      embeddedCliProcess(getCliPointer());
      SampleBatteryVoltage();
      HAL_Delay(1);
      // HAL_I2C_Master_Transmit(&hi2c2,10,TX_Buffer,1,1000); //Sending in Blocking mode

  }
  /* USER CODE END 3 */
}

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
/* USER CODE BEGIN 4 */

void HAL_GPIO_EXTI_Falling_Callback(uint16_t GPIO_Pin)  {
    cli_printf("Clicked with PIN: %u", GPIO_Pin);
    HAL_GPIO_TogglePin(ORANGE_LED_GPIO_Port, ORANGE_LED_Pin);
    for (uint8_t displayNumber = 1; displayNumber <= 4; displayNumber++) {
        SegmentDisp_SetCountdown(14, displayNumber);
    }
}

/* USER CODE END 4 */
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


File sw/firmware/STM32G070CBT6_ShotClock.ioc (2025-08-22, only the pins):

Mcu.UserName=STM32G070CBTx
PA0.GPIO_Label=ADC_BATT_IN
PA0.Signal=ADC1_IN0
PA13.Signal=SYS_SWDIO
PA14-BOOT0.Signal=SYS_SWCLK
PA9.Signal=S_TIM1_CH2
PB0.GPIO_Label=BOOT0_IN
PB0.Signal=GPIO_Input
PB10.GPIO_Label=BUTTON1_INT
PB10.Signal=GPXTI10
PB11.GPIO_Label=BUTTON2_INT
PB11.Signal=GPXTI11
PB12.GPIO_Label=BUTTON3_INT
PB12.Signal=GPXTI12
PB13.GPIO_Label=ORANGE_LED
PB13.Signal=GPIO_Output
PB6.Signal=USART1_TX
PB7.Signal=USART1_RX
PB8.Signal=USART3_TX
PB9.Signal=USART3_RX
PC13.GPIO_Label=BOOT0_IN
PC13.Signal=GPIO_Input
PC7.GPIO_Label=TLC59116_RESETn
PC7.Signal=GPIO_Output

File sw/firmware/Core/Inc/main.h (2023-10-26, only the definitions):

#define BOOT0_IN_Pin GPIO_PIN_13
#define BOOT0_IN_GPIO_Port GPIOC
#define ADC_BATT_IN_Pin GPIO_PIN_0
#define ADC_BATT_IN_GPIO_Port GPIOA
#define BOOT0_INB0_Pin GPIO_PIN_0
#define BOOT0_INB0_GPIO_Port GPIOB
#define BUTTON1_INT_Pin GPIO_PIN_10
#define BUTTON1_INT_GPIO_Port GPIOB
#define BUTTON1_INT_EXTI_IRQn EXTI4_15_IRQn
#define BUTTON2_INT_Pin GPIO_PIN_11
#define BUTTON2_INT_GPIO_Port GPIOB
#define BUTTON2_INT_EXTI_IRQn EXTI4_15_IRQn
#define BUTTON3_INT_Pin GPIO_PIN_12
#define BUTTON3_INT_GPIO_Port GPIOB
#define BUTTON3_INT_EXTI_IRQn EXTI4_15_IRQn
#define ORANGE_LED_Pin GPIO_PIN_13
#define ORANGE_LED_GPIO_Port GPIOB
#define TLC59116_RESETn_Pin GPIO_PIN_7
#define TLC59116_RESETn_GPIO_Port GPIOC

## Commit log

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2023-07-09 Changed documentation, added to schematics
    Added Vbat connection via LDO
    Added jumper to enable/disable the TEMP pin of chrg IC.
    Added PDF exports of schematics
    [LipoBattAndCharger.kicad_sch, STM32F103RCT6_Subsheet.kicad_sch]
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2023-07-10 Fixed all ERC issues
    Mainly by placing PWR_FLAGs and NetTies to show KiCAD where the GNDs are connected to each other physically, without them being the same net.
    [LipoBattAndCharger.kicad_sch, Regulator3V3.kicad_sch, STM32F103RCT6_Subsheet.kicad_sch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]
2023-07-12 Init of SW, changes on HW
    SW init STMIDE project
    HW Added first few footprints for passive components.
    Removed old name .IOC file
    [LipoBattAndCharger.kicad_sch, Regulator3V3.kicad_sch, STM32F103RCT6_Subsheet.kicad_sch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]
2023-07-12 Finished footprint selection & updated design doc
    Chosen all footprints
    Updated design doc with part link & part selection reasons
    [LipoBattAndCharger.kicad_sch, Regulator3V3.kicad_sch, STM32F103RCT6_Subsheet.kicad_sch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]
2023-07-12 HW changes
    Changed Switches to correct SPDT instead of SPST.
    Added design requirements to PCB according to JLCPCB specs
    [STM32F103RCT6_Subsheet.kicad_sch, ShotClockProject.kicad_pcb, ShotClockProject.kicad_sch]
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2023-07-15 Changes headers, usb schematic and footprint
    Now using standing USBc
    Header & header pins are imported
    All have 3d models now.
    Removed fp-info-cache and added it to gitignore
    [STM32F103RCT6_Subsheet.kicad_sch, ShotClockProject.kicad_pcb, header_connectors_segment.kicad_sch]
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2023-07-16 Finished rough layout of PCB (ready for review)
    Changed battery polarity to match the batteries I have.
    Added power led to voltage regulator
    Removed old comments from schematic
    Gave all footprints a 3D model
    Replaced batttery footprint with a SMD JST 3 pins horizontal connector
    Finished rough placement of components
    [LipoBattAndCharger.kicad_sch, Regulator3V3.kicad_sch, STM32F103RCT6_Subsheet.kicad_sch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]
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2023-08-14 Changed pinouts
    To only use 1 pwm per display, and GPIo outs for the rest in both HW and firmware
    [LipoBattAndCharger.kicad_sch, STM32F103RCT6_Subsheet.kicad_sch, ShotClockDisplayPCB.kicad_pcb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]
2023-08-16 Started on second PCB, and added 5V regulator
    5V regulator added to main pcb for the segment displays, using same TPS63000 chip, but with a different selector resistor to choose for 5V
    Added second project to contain the display PCBA design.
    Calculated the current usage of the displays with different current limiting resistors on the LEDs.
    Calculated the current limit resistors for transistors behind LEDs
    [Regulator3V3.kicad_sch, Regulator5V.kicad_sch, ShotClockDisplayPCB.kicad_pcb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]
2023-08-16 Finshed both schematics
    - LED driving transistors are placed
    - All connectors on segment display PCB are placed
    - All schematic references have been re-configured (autosort on Y axis)
    [LipoBattAndCharger.kicad_sch, Regulator3V3.kicad_sch, Regulator5V.kicad_sch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]
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2023-09-10 Redid layout with new board dimensions
    Changed tactile switches to larger push switches (also momentary)
    Changed USART1 to UART4 & added UART5 to STDC14 connector
    Placed all components nearer to each other, and within the PCB outer edge
    Added rounded corners
    [LipoBattAndCharger.kicad_sch, STM32F103RCT6_Subsheet.kicad_sch, SchmittTriggerWithButtons.kicad_sch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]
2023-09-10 Moved components further from edge
    Also changed hole size, hole placement further from edge and other small dimensional changes
    [ShotClockProject.kicad_pcb]
2023-09-10 Started on routing
    Started with decoup caps, sensitive signals and simple GPIO
    [ShotClockProject.kicad_pcb]
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2023-09-13 Added USB ESD protection
    Removed testpoints for USB+ and USB-
    Removed routes to display connectors, for another try
    [STM32F103RCT6_Subsheet.kicad_sch, ShotClockProject.kicad_pcb]
2023-09-13 Fixed buzzer footprint
    Almost done routing, 14 conn left.
    [STM32F103RCT6_Subsheet.kicad_sch, ShotClockProject.kicad_pcb]
2023-09-13 Finished routing
    Added assembly holes
    Added JLCJLCJLCJLC tag to hide their order number
    [ShotClockProject.kicad_pcb]
2023-09-13 Added LCSC Part number
    Renamed output folders
    Created first output files for REV1
    [LipoBattAndCharger.kicad_sch, Regulator3V3.kicad_sch, Regulator5V.kicad_sch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]
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2023-09-14 Display print
    Changed mainboard connector to FPC connector
    Created routing for board
    [ShotClockDisplayPCB.kicad_pcb, ShotClockDisplayPCB.kicad_sch, led_drv_trns.kicad_sch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]
2023-09-19 Added LCSC part numbers, and changed TPS vias
    - Changed the footprint for the TPS regulators, so they don't have 0.2mm vias. Manually placed GND vias next to the footprint.
    - Removed NETTIES to get rid of weird across the map connection of GND and GNDPWR.
    [Regulator3V3.kicad_sch, Regulator5V.kicad_sch, ShotClockProject.kicad_pcb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]
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2023-09-20 Start on REV2
    Decided to use 16 bit PWM IO expanders for segment displays
    Chose another STM, because F1 is out of stock (STM32G070CBT6 now)
    Replaced STM32Cube configuration with new config for G0 series.
    Updated docs to reflect new parts.
    [LipoBattAndCharger.kicad_sch]
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2023-09-23 Added I2C support
    Calculated pull-up resistor values
    Added 6 pin female headers to mainboard
    Added nRESET line for the I2C chips
    Removed PCB routing and part placement
    [LipoBattAndCharger.kicad_sch, Regulator3V3.kicad_sch, Regulator5V.kicad_sch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]
2023-09-23 Cleaned second print
    and added new connectors, pinout and removed all REV1 stuff.
    [ShotClockDisplayPCB.kicad_pcb, ShotClockDisplayPCB.kicad_sch, ShotClockProject.kicad_pcb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]
2023-09-25 Changed display connectors to JST PH 2.0mm
    In docs, schematic and footprints
    Both sides, connect with male/male cable
    [ShotClockDisplayPCB.kicad_pcb, ShotClockProject.kicad_pcb, header_connectors_segment.kicad_sch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]
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2023-10-02 Finished mainboard routing
    Reconfigered pins to make routing easier/cleaner
    Placed copper fills as much as possible to create an even plating index
    [LipoBattAndCharger.kicad_sch, STM32G070CBT6.kicad_sch, SchmittTriggerWithButtons.kicad_sch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]
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2023-10-03 Started on display board rework
    added new footprints
    added HW select shunts/jumpers
    [ShotClockDisplayPCB.kicad_pcb, ShotClockDisplayPCB.kicad_sch, i2c_pwm_io_expander.kicad_sch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]
2023-10-04 Redid routing on disp PCB
    Added TLC chip
    Routed everything
    Used way more filled areas
    [ShotClockDisplayPCB.kicad_pcb, ShotClockDisplayPCB.kicad_sch]
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2023-10-05 Fixed mainboard with feedback from Luc
    [LipoBattAndCharger.kicad_sch, ShotClockDisplayPCB.kicad_pcb, ShotClockDisplayPCB.kicad_sch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]
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2023-10-07 REV2 Finished
    Corrected LCSC part number
    Added polarities on silkscreen
    Made output files for both boards
    Added forgotten drill files
    [ShotClockDisplayPCB-B_Cu.gbr, ShotClockDisplayPCB-B_Mask.gbr, ShotClockDisplayPCB-B_Paste.gbr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]
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2023-10-26 Added enabling of Buzzer & button itnerrupts
    [STM32G070CBT6_ShotClock.ioc, cli_binding.c, main.c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]
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2024-02-12 Add adc, addressable displays, cntdown
    ADC for voltage readout start(non correct value currently)
    All 4 sets of 2 displays are seperatly addressable now.
    Add timer function to countdown from x to 0 (currently on all 4 displays only)
    [STM32G070CBT6_ShotClock.ioc, TLC59116.c, adc.c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]
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2025-08-22 Add REV3 odt file, update CubeMX version and fix the ADC readout for battery voltage.
    [LipoBattAndCharger.kicad_sch, Regulator3V3.kicad_sch, Regulator5V.kicad_sch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]
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

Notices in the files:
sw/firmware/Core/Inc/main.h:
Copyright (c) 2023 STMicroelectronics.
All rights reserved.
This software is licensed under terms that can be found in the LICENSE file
